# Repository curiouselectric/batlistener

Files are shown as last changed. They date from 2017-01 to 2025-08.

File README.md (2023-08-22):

# Bat Listener
Design files for the Bat Listener kit as sold by https://www.curiouselectric.co.uk/

The kit is available to purchase here:
https://www.curiouselectric.co.uk/products/bat-listener-2016

This repository holds the design files for the PCB, the enclosure and the instructions

The PCB files have been designed using KiCAD (http://kicad.org/) which is open source, multiple platform and free to download.

The Enclosure design files have been produced using CorelDraw (a paid for program) but are aklso available as .dxf patterns for cutting on a laser cutter.

The instructions are available as an open-office document and as a .pdf for direct download.

Any comments or info please email: hello@curiouselectric.co.uk

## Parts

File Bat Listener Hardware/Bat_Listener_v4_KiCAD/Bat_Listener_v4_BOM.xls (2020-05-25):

Reference | Value | Footprint | Datasheet | Description | Manufacturer | Manufacturer Part No
BT1 | BATTERY | REInnovationFootprint:Batt_Connector_Strain_Relief |  | PP3 Connector
C1 | 100u | REInnovationFootprint:C_1V7_TH
C10 | 1n | matts_components:C1_wide_lg_pad
C11 | 33n | matts_components:C1_wide_lg_pad
C12 | 470p | matts_components:C1_lg_pad
C13 | 470p | matts_components:C1_lg_pad
C14 | 100n | matts_components:C1_wide_lg_pad
C15 | 100u | REInnovationFootprint:C_1V7_TH
C16 | 100p | matts_components:C1_lg_pad
C2 | 100u | REInnovationFootprint:C_1V7_TH
C3 | 220n | matts_components:C1_wide_lg_pad
C4 | 47n | matts_components:C1_wide_lg_pad
C5 | 220u | REInnovationFootprint:C_1V7_TH
C6 | 47n | matts_components:C1_wide_lg_pad
C7 | 2n2 | matts_components:C1_wide_lg_pad
C8 | 1n5 | matts_components:C1_wide_lg_pad
C9 | 100p | matts_components:C1_lg_pad
D1 | 5V1 ZENER | REInnovationFootprint:TH_Diode_1 |  | 500mW 5V1 Zener
D2 | 1N4148 | REInnovationFootprint:TH_Diode_1
D3 | 1N4148 | REInnovationFootprint:TH_Diode_1
D4 | SENSE | reinnovation-footprints:TH_LED-5MM_larg_pad |  | LED Red 5mm
P1 | ULTRASON | reinnovation-footprints:TH_Ultra_sonic_Rx |  | 40kHz Ultrasonic Rx
P10 | LOGO1 | CuriousElectric3:TCEC_Words_13mm
P11 | LOGO2 | CuriousElectric3:CuriousElectric_globe_10mm
P12 | Hex_Spacer |  |  | 6 x HEX spacer 9mm M3 M-F
P2 | uP O/P | reinnovation-footprints:TH_Pin_Header_Straight_1x02
P3 | NO_Pb | REInnovationGraphics:PH_LOGO_NO_Pb
P4 | BAT | CuriousElectric3:Bat_Logo
P5 | PCB | reinnovation-footprints:PCB_50x100mm_PP3_CutOut
P6 | Enclosure
P7 | O/P | matts_components:SIL-2_lg_pad_1mm
P8 | Screws |  |  | 12 x M13 10mm Machine screws
P9 | Hex_Spacer |  |  | 6 x HEX spacer 9mm M-M
Q1 | BC337 | REInnovationFootprint:TO92-EBC_large_pad |  | NPN Transistor
R1 | 47k | REInnovationFootprint:TH_Resistor_1
R10 | 560k | REInnovationFootprint:TH_Resistor_1
R11 | 100 | REInnovationFootprint:TH_Resistor_1
R12 | 10k | REInnovationFootprint:TH_Resistor_1
R14 | 1k | REInnovationFootprint:TH_Resistor_1
R2 | 47k | REInnovationFootprint:TH_Resistor_1
R3 | 10 | REInnovationFootprint:TH_Resistor_1
R4 | 1k3 | REInnovationFootprint:TH_Resistor_1
R5 | 150k | REInnovationFootprint:TH_Resistor_1
R6 | 100k | REInnovationFootprint:TH_Resistor_1
R7 | 1k | REInnovationFootprint:TH_Resistor_1
R8 | 1k | REInnovationFootprint:TH_Resistor_1
R9 | 470k | REInnovationFootprint:TH_Resistor_1
RV1 | 22k | reinnovation-footprints:TH_PRESET_Thumb_Side |  | 20k Variable Resistor
SP1 | SPEAKER | reinnovation-footprints:TH_SPEAKER_36mm |  | 0.5W 8 ohm 36mm Speaker
SW1 | ON/OFF | reinnovation-footprints:SW_SPDT_R_Angle_ALIEX |  | Right Angle On/Off Slide Switch
U1 | LM386 | REInnovationFootprint:DIP-8_300_ELL | https://www.rapidonline.com/pdf/82-0264e.pdf | 325mW Power Amplifier | National Semiconductor | LM386N-1
U2 | TL074A | matts_components:DIP-14__300_ELL_lg_pad | https://www.rapidonline.com/pdf/82-0054_v1.pdf | Quad Op-Amp Bi-FET | Texas Instruments | TL074CN
U3 | 4024 | matts_components:DIP-14__300_ELL_lg_pad | https://www.rapidonline.com/pdf/83-0354_v1.pdf | 7 Stage Binary Counter | Texas Instruments | CD4024BE

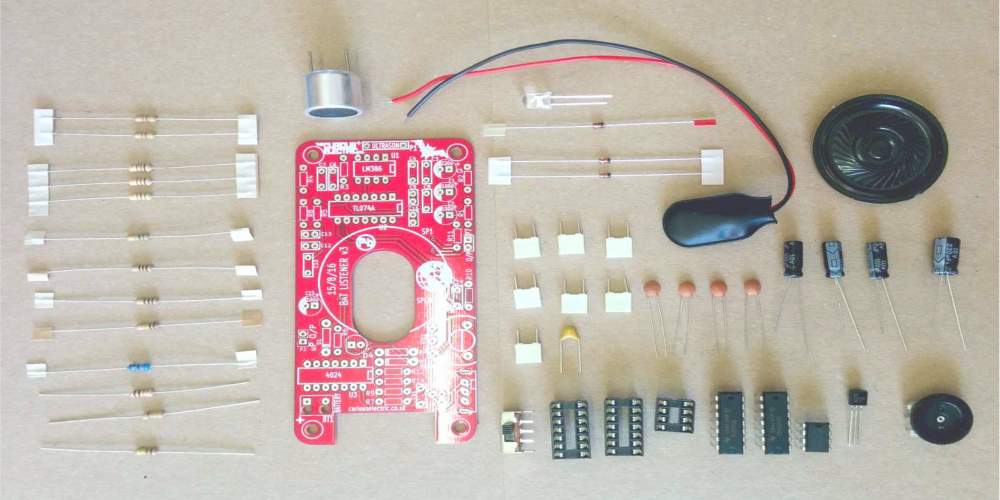
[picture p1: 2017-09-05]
Bat Listener Instructions/Photos/parts1_1000x5000.jpg

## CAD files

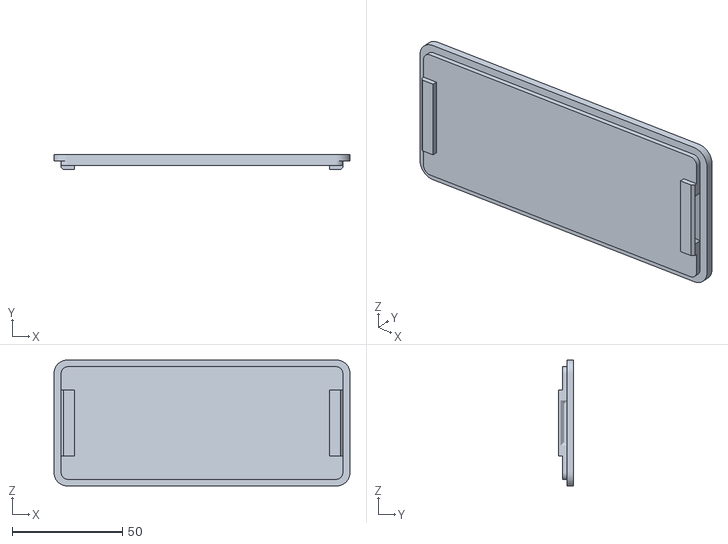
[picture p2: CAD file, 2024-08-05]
Bat_Listener_Enclosure/User Designed Cases/3D Printed Enclosure - Andy Evans/Ultrasonic Case Lid.stl
134.0 x 7.00 x 57.0

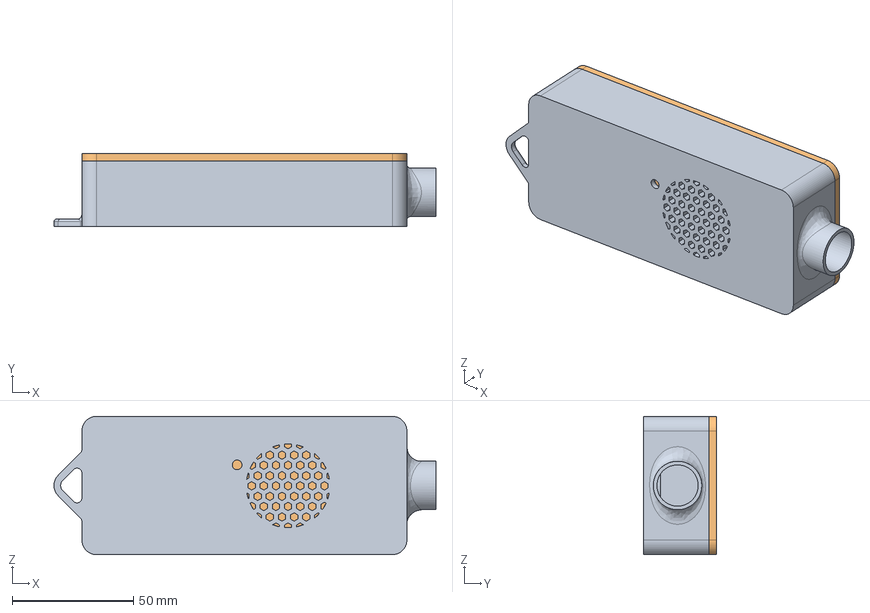
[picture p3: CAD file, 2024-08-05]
Bat_Listener_Enclosure/User Designed Cases/3D Printed Enclosure - Andy Evans/Ultrasonic Case.step
157.5 x 30.0 x 57.0 mm
Ultrasonic Case_1
Ultrasonic Case Lid

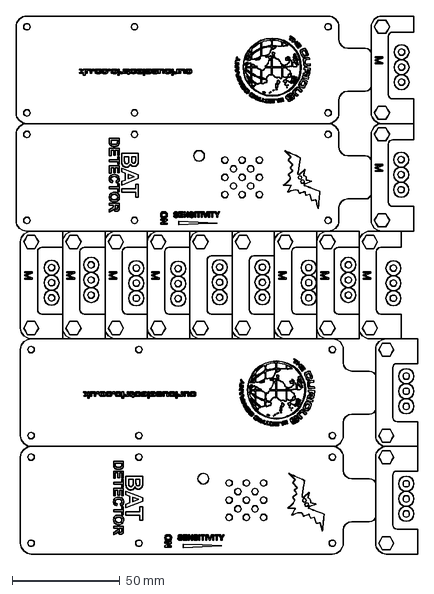
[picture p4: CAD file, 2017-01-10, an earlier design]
Bat_Listener_Enclosure/Curious Electric Standard Case/OLD/Bat Listener 2016 Enclosure v4.dxf
186.7 x 250.0 mm

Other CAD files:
Bat_Listener_Enclosure/User Designed Cases/3D Printed Enclosure - Andy Evans/Ultrasonic Case.stl

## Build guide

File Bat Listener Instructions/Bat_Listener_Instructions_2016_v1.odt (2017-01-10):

` | Bat Detector Kit Instructions

Date: | 18/10/16 | Version: | 1.0 | By: | Matt Little

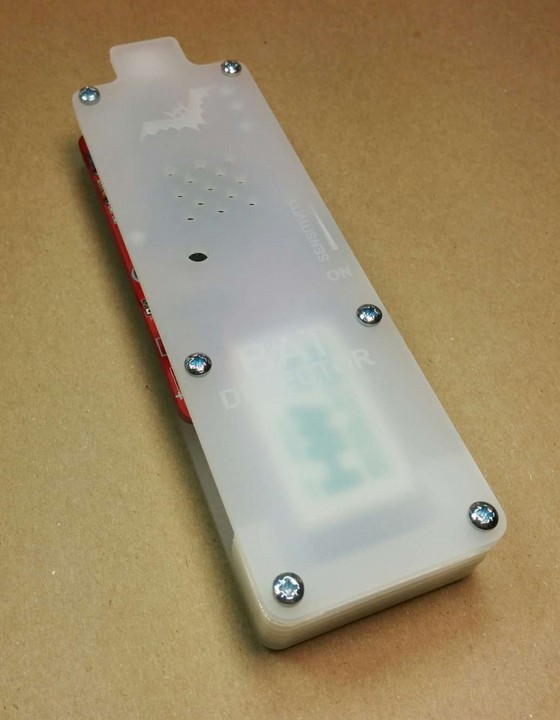
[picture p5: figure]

| Build your own Bat Detector! Bats use ultra-sonic pulses to navigate and to detect prey. These pulses are very high pitch (around 5 times the maximum frequency humans can hear). This electronic circuit converts the high pitched sounds produced by bats to a human-audiable level. It has a sensitivity control to adjust for different conditions. It can also be used to listen to other high frequencies such as peeling sticky tape, compact fluorescent lights and power supplies. This kit, although easy to build, requires quite a lot of soldering so will take in the region of 2-3 hours.

Parts included:

| | | Ultrasonic receiver | | LED | 5.1V Zener
| | | | | | | | 2 x 1N4148 Diodes
| | | | | | | | Speaker
| | | | | | | | PP3 battery clip
13 x Resistors | | | | | | | | 16 x Capacitors
| | | | | | | | Potentiometer
| | | | | | | | Transistor
| | PCB | | Switch | 3 x IC holders | 3 x ICs

Enclosure Parts:

Front | | 4 x spacers
Back
2mm end | | 6 x M3 Hex Spacers
4 x 3mm wide cut-out end
3mm end | | 6 x M3 12mm machine screws
| | 6 x M3 6mm machine screws

Parts list:

Item | Ref | Item | Ref
PP3 Battery Clip | BT1 | 47k Resistor | R1, R2
100uf Capacitor | C1, C2, C15 | 10 ohm Resistor | R3
220nf Capacitor | C3 | 1.3k Resistor | R4
47nf Capacitor | C4, C6 | 150k Resistor | R5
220uf Capacitor | C5 | 100k Resistor | R6
2.2nf Capacitor | C7 | 1k Resistor | R7,R8,R14
1.5nf Capacitor | C8 | 470k Resistor | R9
100pf Capacitor | C9, C16 | 560k Resistor | R10
1nf Capacitor | C10 | 100 ohm Resistor | R11
33nf Capacitor | C11 | 10k Resistor | R12
470pf Capacitor | C12,C13 | 20k Potentiometer | RV1
100nf Capacitor | C14 | 40mm Loudspeaker | SP1
5.1V Zener Diode | D1 | Switch | SW1
1N4148 small signal Diode | D2,D3 | LM386 Audio Amplifier IC | U1
5mm Red LED | D4 | TL074A Quad-comparator IC | U2
Ultrasonic Receiver | P1 | 4024 Counter IC | U3
BC337 Transistor | Q1
Enclosure
Front | x1 | 3mm PCB spacer rings | x4
Back | x1 | M3 Hex spacers 9mm | x6
2mm Clear Spacer | x1 | M3 6mm machine screws | x6
3mm Wide Spacer (marked "M") | x4 | M3 10mm machine screws | x6
3mm narrow spacer | x1

Tools required:

PCB Instructions:

Step: 1 | Solder resistors

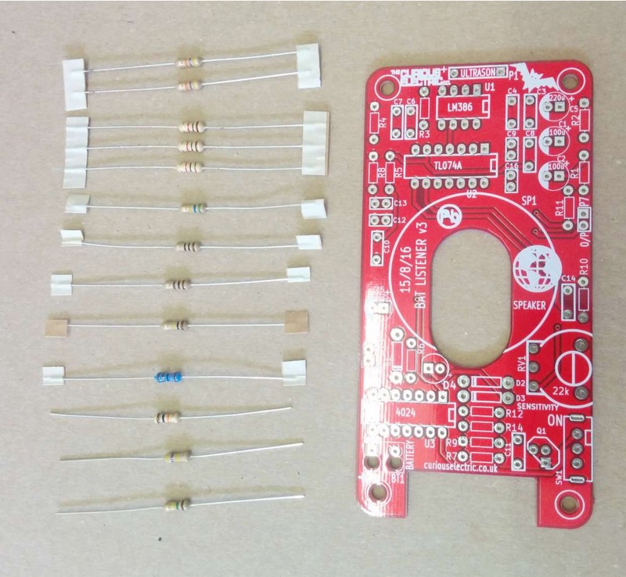
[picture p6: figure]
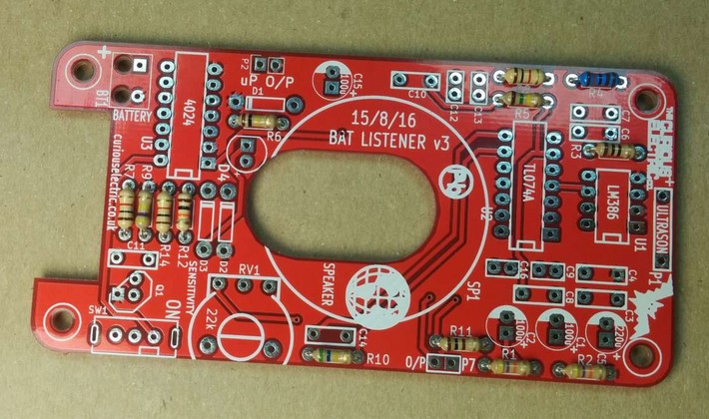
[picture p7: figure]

| | Value Ref Colour 47k R1, R2 Yellow, Violet, Orange, Gold 10 R3 Brown, Black, Black, Gold 1.3k R4 Brown, Orange, Red, Gold (This resistor is blue) 150k R5 Brown, Green, Yellow, Gold 100k R6 Brown, Black, Yellow, Gold 1k R7,R8,R14 Brown, Black, Red, Gold 470k R9 Yellow, Violet, Yellow, gold 560k R10 Green, Blue, Yellow, Gold 100 R11 Brown, Black, Brown, Gold 10k R12 Brown, Black, Orange, Gold Insert and solder the resistors. Polarity does not matter for resistors. Ensure they are soldered flat close to the PCB. Use a multimeter or colour code chart to ensure correct resistor values.

Step: 2 | Solder capacitors

First solder the non-polarised capacitors.

Orientation of these does not matter:

Value | Ref | Marking
220nf | C3 | .22K63 (cream box)
47nf | C4, C6 | 47nK100 (cream box)
2.2nf | C7 | 2n2K100 (cream box)
1.5nf | C8 | 152 (brown blob)
100pf | C9, C16 | 101 (brown disk)
1nf | C10 | 1nK100 (cream box)
33nf | C11 | 33nK100 (cream box)
470pf | C12,C13 | 471 (brown disk)
100nf | C14 | .1K63 (cream box)

Next solder the polarised capacitors. Ensure correct orientation of these components.

The negative lead is marked with a white strip. The positive lead is slightly longer than the negative. Align the positive lead with the + sign and the negative lead with the white PCB marking.

Value | Ref | Marking
100uf Capacitor | C1, C2, C15 | 10V 100uf
220uf Capacitor | C5 | 16V 220uf

Step: 3 | Solder diodes

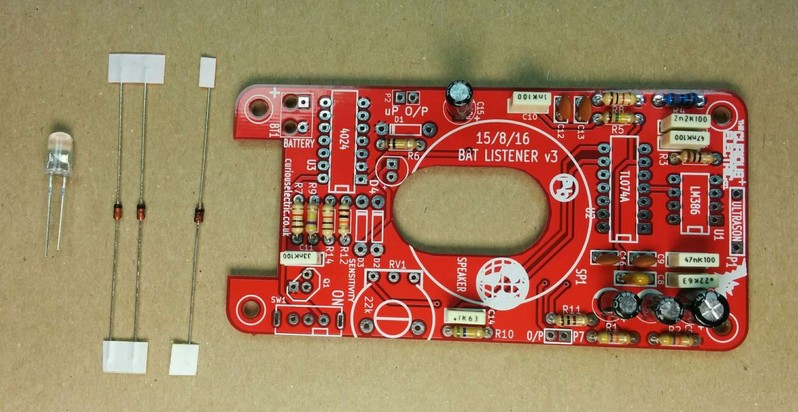
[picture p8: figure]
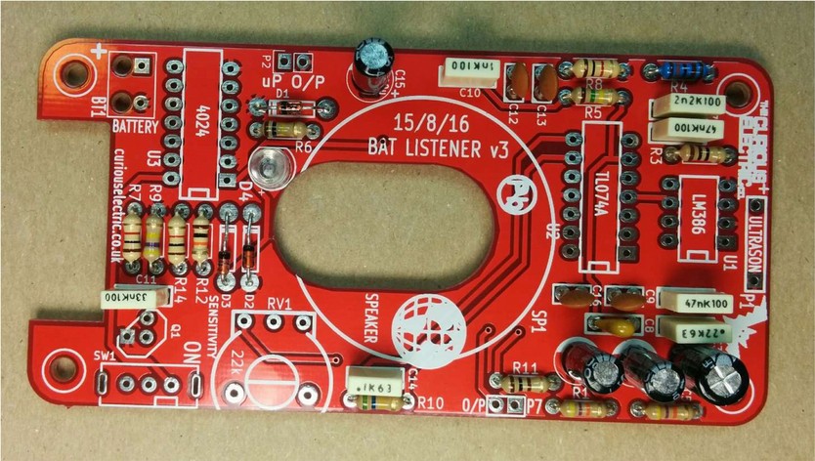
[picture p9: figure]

| | There are 4 diodes to solder. Ensure correct orientation for these components. First solder the LED into D4. The long lead is positive, so place that into the hole marked +. The negative side is slightly flat. Then solder the 5.1V zener diode into D1. This diode is on its own and has very tiny marking of “5V1”. Ensure the black band aligns with the white band marked on the PCB. The solder the remaining 2 diodes into D2 and D3. These have tiny markings saying “4148”. Ensure the black band aligns with the white band marked on the PCB.

Step: 4 | Solder transistor

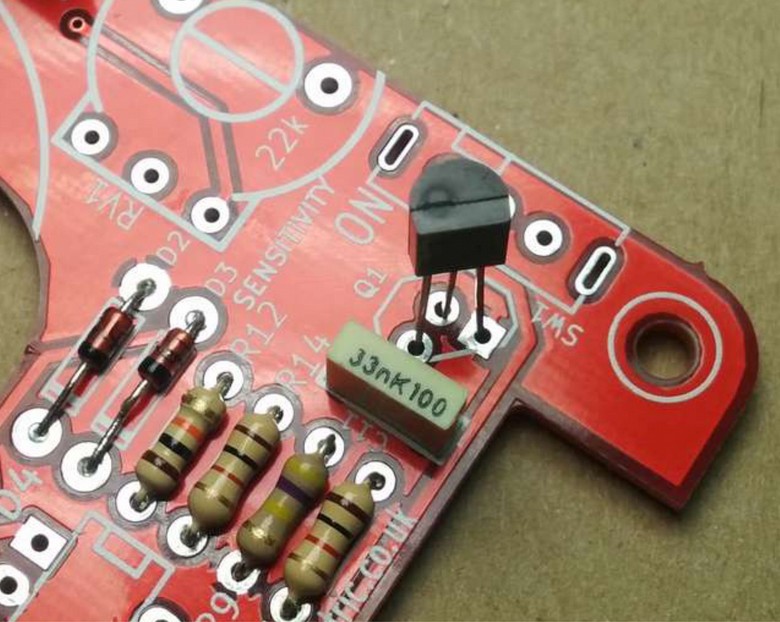
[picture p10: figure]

There is just one transistor to solder, Q1, BC337. Ensure the flat side of the transistor aligns with the PCB markings.

Step: 5 | Solder IC holders

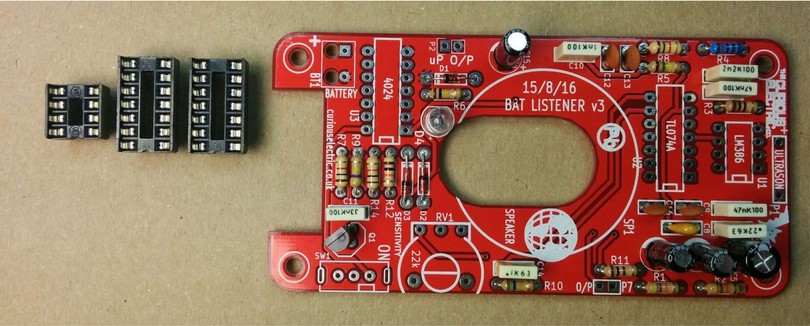
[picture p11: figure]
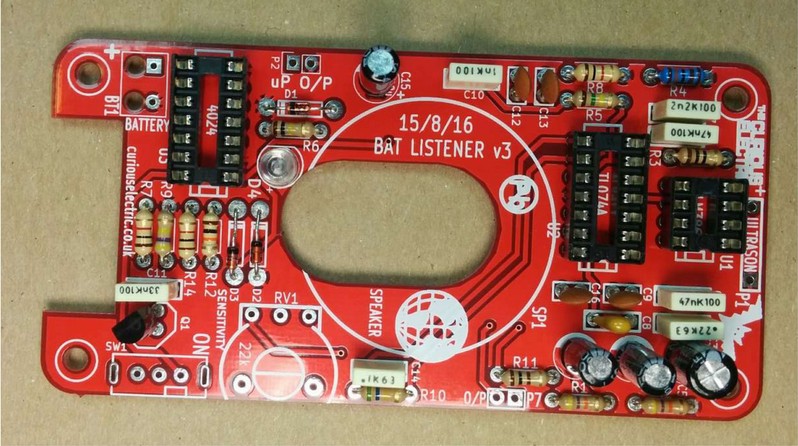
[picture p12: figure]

| | There are two 14pin IC holders and one 8 pin IC holder. These fit into the areas marked U1, U2 and U3. Ensure correct orientation! Ensure the notch on the holder aligns with the notch shown on the PCB.

Step: 6 | Solder Switch and Potentiometer

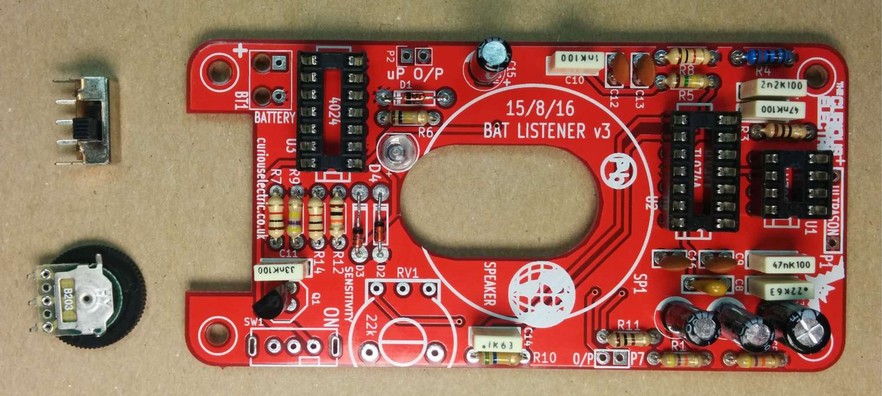
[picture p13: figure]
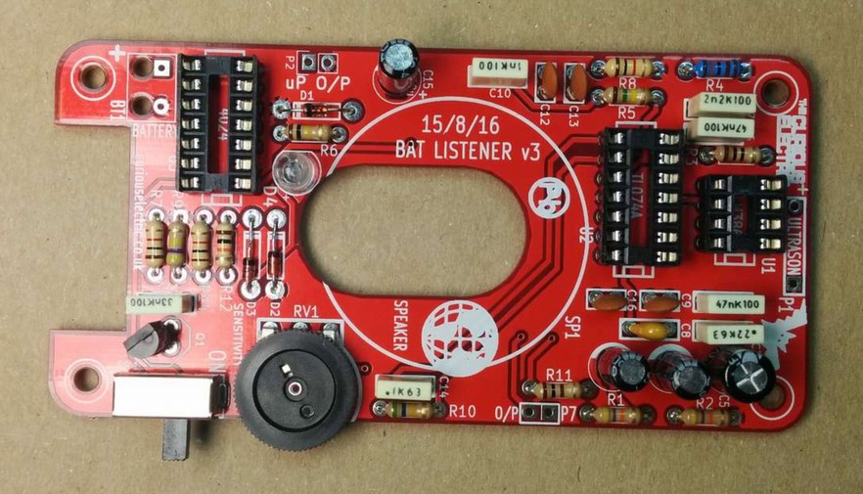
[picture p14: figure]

The switch fits into the holes marked SW1. The switch knob goes off the PCB. Solder all metal tabs. The potentiometer fits into the holes marked RV1. There are 5 pins to align and the pins might need slightly moving to ensure they align correctly. Solder all metal tabs.

Step: 7 | Solder Speaker

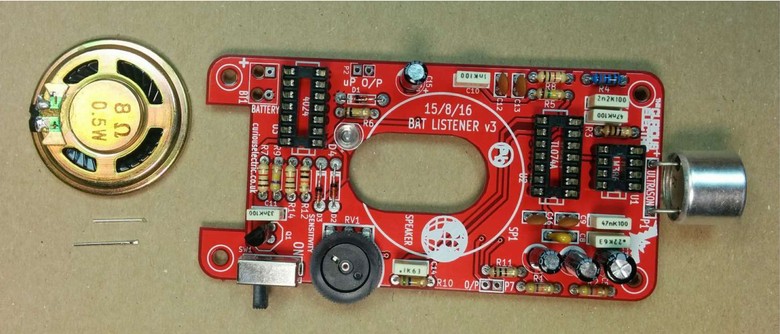
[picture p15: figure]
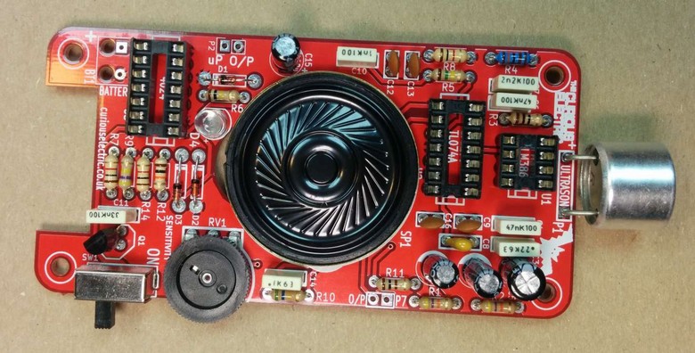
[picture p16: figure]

| | The speaker has a slightly unusual mounting method. The speaker base fits through the large hole in the PCB and the speaker tabs alight with the PCB tabs. Use an offcut of resistor lead and solder two small leads from the PCB (as shown). Then pt the speaker in place and solder the small wires to the speaker. This method holds the speaker in place, as well as being the electrical connection.

Step: 8 | Solder PP3 battery connector

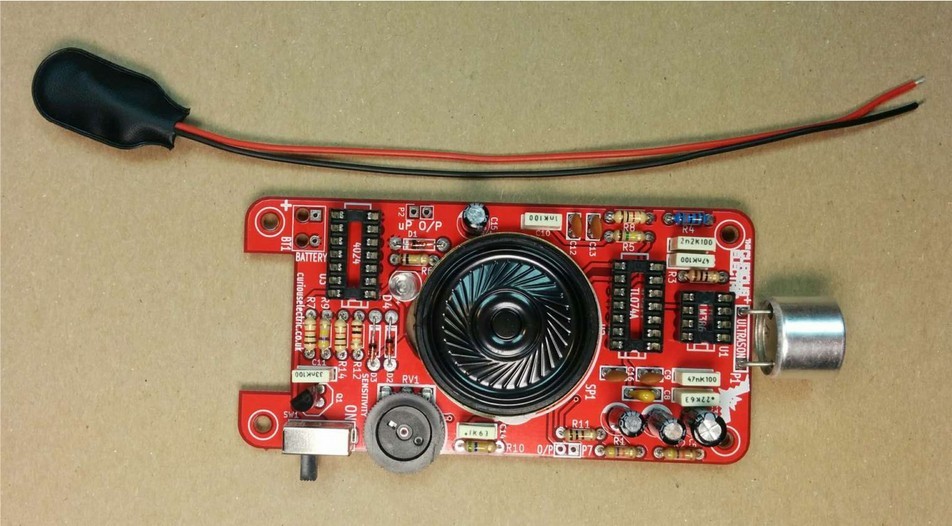
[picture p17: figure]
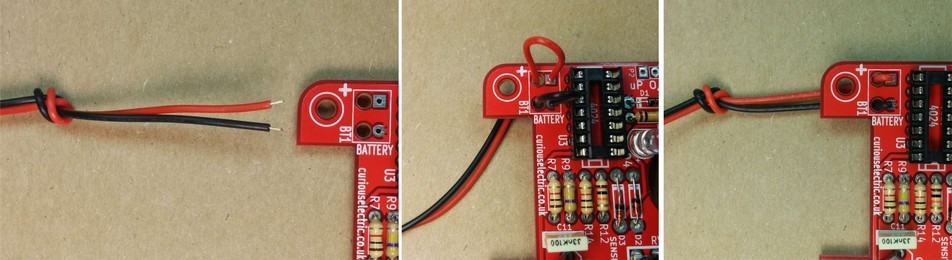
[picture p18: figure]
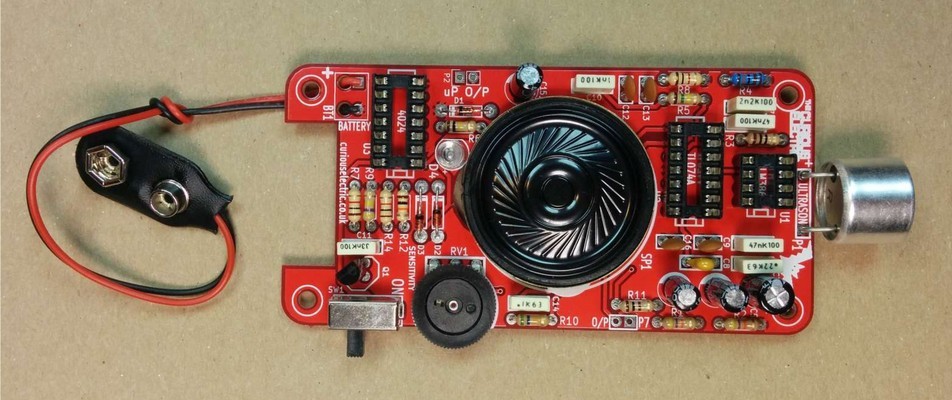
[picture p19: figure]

Nearly there! The PP3 battery clip as two wires: one positive (red) and one negative (black). I usually put a knot in the cable for strain relief. The cables then go through the larger holes and are fed back into the solder pads. The red cable goes through the hole to the pad marked “+”.

Step: 9 | Insert ICs

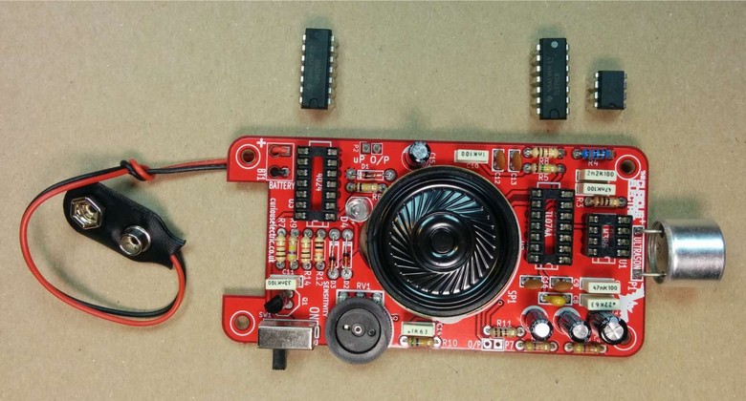
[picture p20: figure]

| | Now we need to insert the ICs into their holders. Ensure the notches align with the notches on the IC holders and the PCB. U1 is the LM386 (8 pin) U2 is the TL074A (14 pin) U3 is the 4024 (14 pin)

Step: 10 | Insert battery and test
Add a PP3 9V battery to the battery clip. Switch the unit on. You may hear a squeal from the device. Adjust potentiometer until you just do not hear any noise. The red LED should also flash when the speaker clicks. Use a reel of sticky tape to test. Slowly peel the tape off the reel and you should hear crackles from the speaker. This is picking up high frequency sound from the glue breaking. You can also test by pointing at a compact fluorescent light bulb. These switch at around 100kHz and hence give off ultrasonic noise.

Step: 16 | PCB is finished!
| | Have a nice cup of tea.

Enclosure Instructions:

Step: 1 | Push out laser-cut parts and peel off protective layer

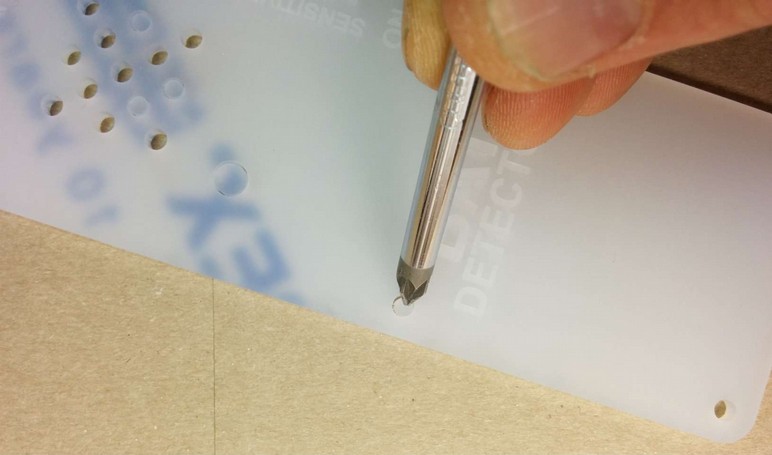
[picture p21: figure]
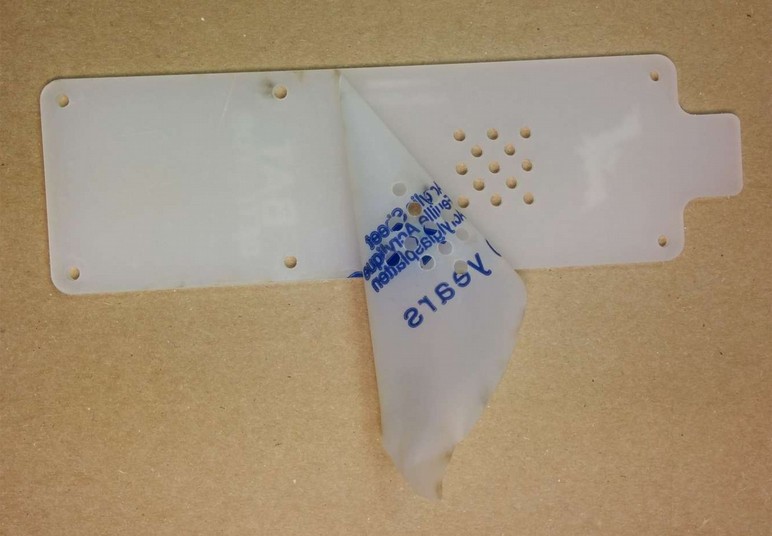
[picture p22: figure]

Sometimes not all the small laser-cut pieces have been removed. These can be pushed out using the point of a screwdriver. Only slight force should be required. There is a protective film on one side of the laser cut parts. This can be removed by peeling off the film.

Step: 2 | Screw down the PCB

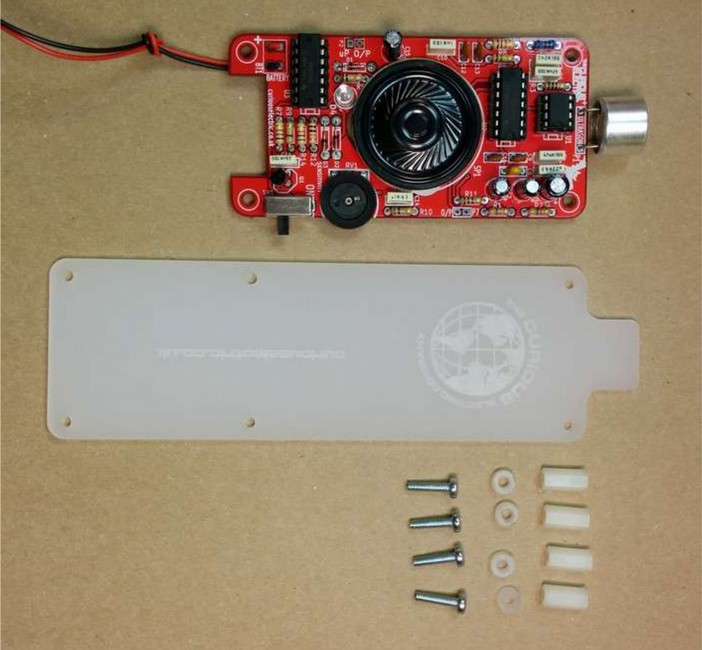
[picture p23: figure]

| | The PCB is held onto the back plate using the M3 10mm screws and the hex spacers. The back plate has the text facing to the back. The screws fit through the back plate then through a small circular spacer ring and then through the PCB. It is then held in place using the threaded hex spacer. Do this for all four corners of the PCB.

Step: 3 | Add end spacers

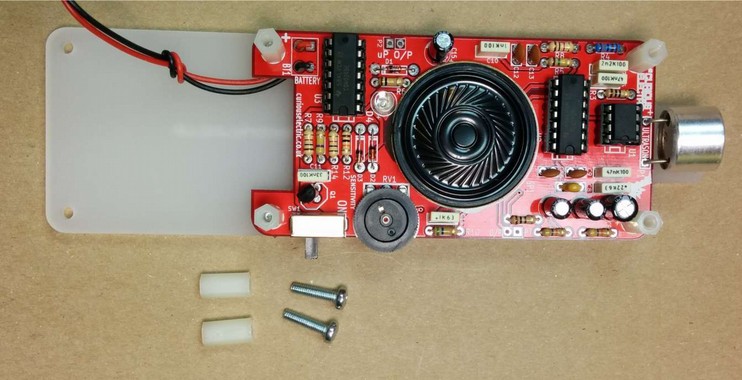
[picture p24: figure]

To hold the end spacers in place we again use the 10mm screws and 2 of the hex spacers. Put them through the back plate and slightly screw the hex spacer onto the screw. Do not fully tighten this, as it will need to spin to be adjusted in the next step.

Step: 4 | Add battery holders

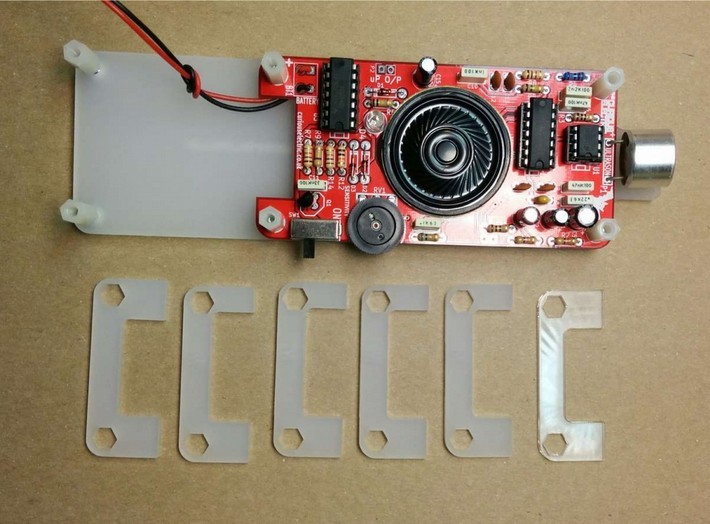
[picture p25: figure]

| | The battery holders are 6 spacers which holds one end of the battery, with the other end being held the notch in the PCB. There are three types of spacer: 1 x narrow 3mm spacer (in white frosted plastic) 4 x wide 3mm spacers (with an “M” etched on them). 1 x narrow 2mm spacer in clear plastic. These fit onto the hex spacers we just added. First add the narrow 3mm piece. Then the 4 wide 3mm pieces (marked “M”). Put the battery into the enclosure. The PP3 battery clip fits within the wider section, with the cable able to come out of the side. The final narrow 2mm space is put on top.

Step: 5 | Fit top cover

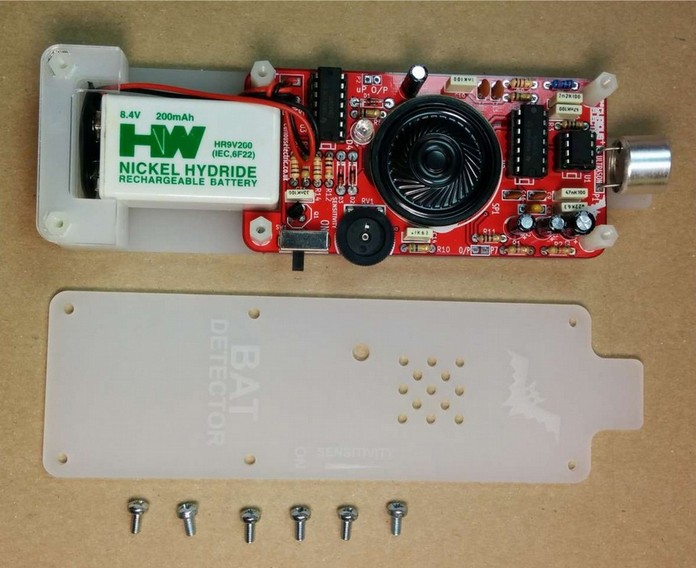
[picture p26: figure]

The front cover is then put on with the text facing upwards. Use the final 6 x 6mm M3 machine screws to hold the front cover in place. These fasten into the threaded hex spacers. Note: Some covers do not have the hole for the LED. The LED can be seen through the frosted plastic, so it is not needed.

Step: 6 | Finished!

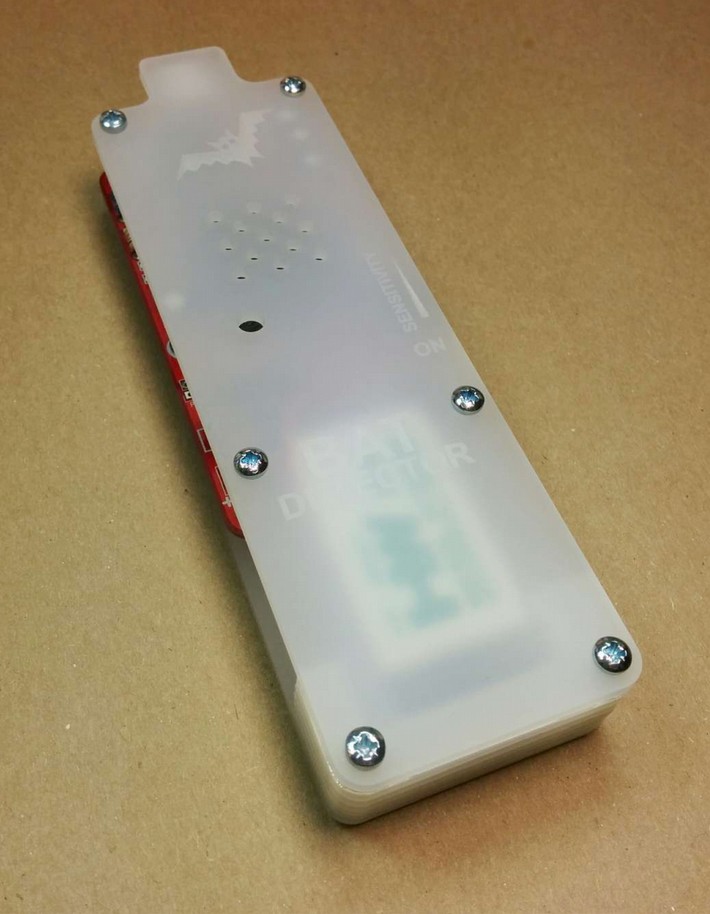
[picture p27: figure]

| | That is the unit finished! The on/off switch and the potentiometer are accessible via the side of the unit. You now have your own bat detector. There are many things you can investigate including: Nature: monitor bats, mice and rats Electrical: Check the sound from switching power supplies and fluorescent lights

Please note: This unit is NOT waterproof. Do NOT leave outside if it will get wet.

Contact details:

We would like you to be happy with this kit. If you are not happy for any reason then please contact us and we will help to sort it out.

Please email hello@curiouselectric.co.uk with any questions or comments.

Please tweet us at @curiouselectric

If any parts are missing from your kit then please email hello@curiouselectric.co.uk with details and, if possible, where the kit was purchased.

More technical information can be found via www.curiouselectric.co.uk

This kit has been designed and produced by:

The Curious Electric Company

hello@curiouselectric.co.uk

www.curiouselectric.co.uk

Hopkinson, 21 Station Street, Nottingham, NG2 3AJ, UK

History

This kit is based upon a circuit originally published by Elektor Electronics:

http://www.elektor.com/magazines/2011/november/simple-bat-detector.1971945.lynkx

and was originally developed as a workshop for Nottingham Hackspace: www.nottinghack.co.uk

Circuit Schematic

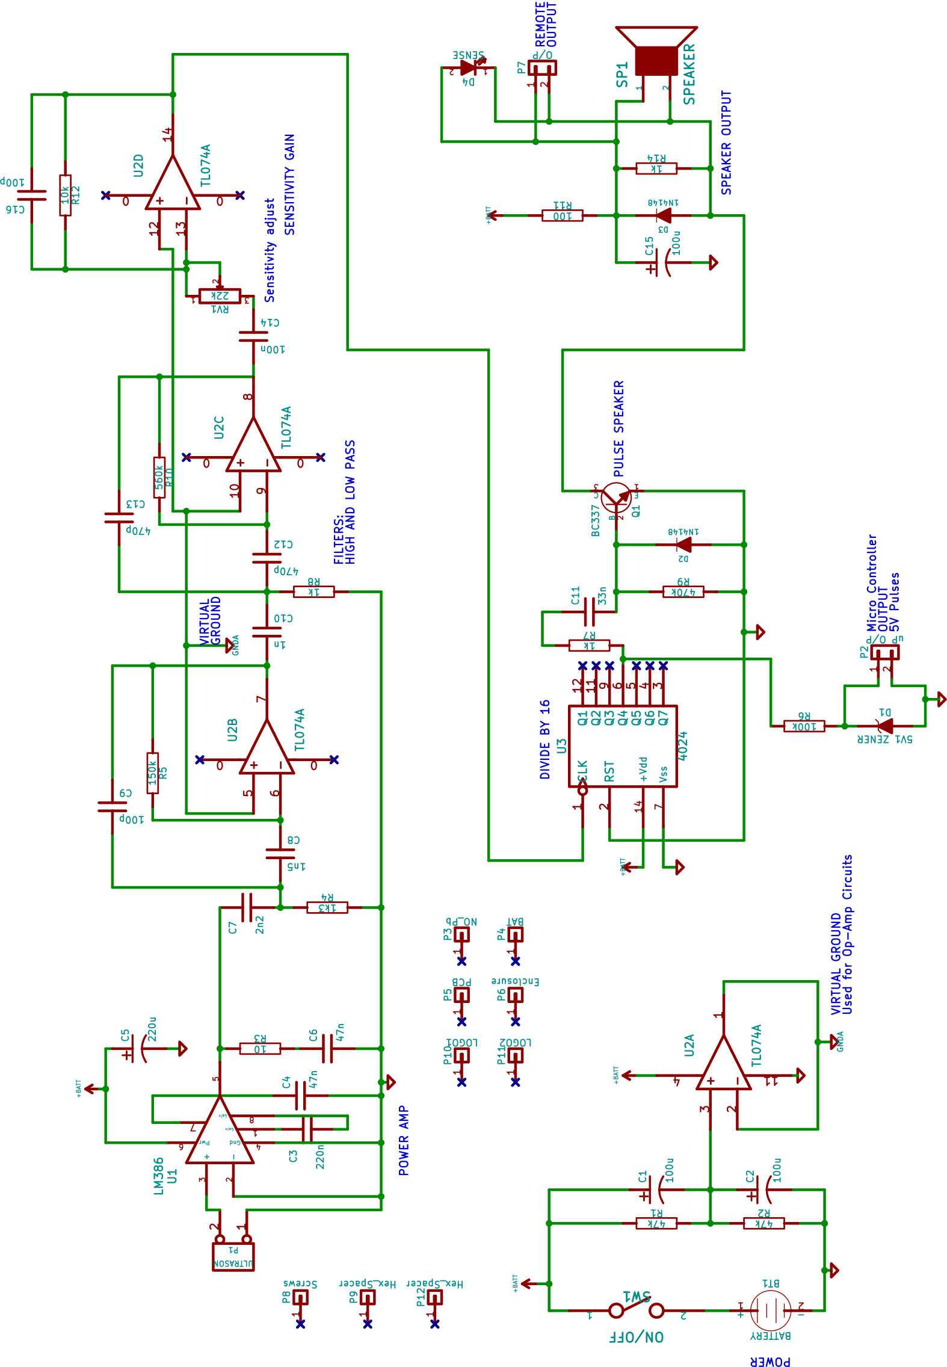
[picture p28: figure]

Resistor Colour Codes

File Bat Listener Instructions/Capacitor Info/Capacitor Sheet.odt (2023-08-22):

Capacitor Information

Due to changes in component suppliers your kit may have different styles of capacitors included.

Value | Ref | Marking | Image | Marking | Image
220nf | C3 | ‘.22K63’ | | ‘224’
47nf | C4, C6 | ‘47nK100’ | | ‘473’
2.2nf | C7 | ‘2n2K100’ | | ‘222’
1.5nf | C8 | ‘152’ | Also in blue
100pf | C9, C16 | ‘101’ | | ‘101’
1nf | C10 | ‘1nK100’ | | ‘102’
33nf | C11, C17 | ‘33nK100’ | Also in dark grey | ‘333’
470pf | C12,C13 | ‘471’ | | ‘471’
100nf | C14 | ‘.1K63’ or ‘.1J63‘ | | ‘104’
100uf | C1, C2, C15 | ‘10V 100uf’ | | Might have different voltages
220uf | C5 | ‘16V 220uf’ | | Might have different voltages

Capacitor Information

Due to changes in component suppliers your kit may have different styles of capacitors included.

Value | Ref | Marking | Image | Marking | Image
220nf | C3 | ‘.22K63’ | | ‘224’
47nf | C4, C6 | ‘47nK100’ | | ‘473’
2.2nf | C7 | ‘2n2K100’ | | ‘222’
1.5nf | C8 | ‘152’ | Also in blue
100pf | C9, C16 | ‘101’ | | ‘101’
1nf | C10 | ‘1nK100’ | | ‘102’
33nf | C11, C17 | ‘33nK100’ | Also in dark grey | ‘333’
470pf | C12,C13 | ‘471’ | | ‘471’
100nf | C14 | ‘.1K63’ or ‘.1J63‘ | | ‘104’
100uf | C1, C2, C15 | ‘10V 100uf’ | | Might have different voltages
220uf | C5 | ‘16V 220uf’ | | Might have different voltages

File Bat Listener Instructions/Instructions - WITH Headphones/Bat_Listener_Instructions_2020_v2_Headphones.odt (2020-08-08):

| Bat Detector Kit Instructions

Date: | 06/08/2020 | Version: | 5.0 | By: | Matt Little


| Build your own Bat Detector! Bats use ultra-sonic pulses to navigate and to detect prey. These pulses are very high pitch (around 5 times the maximum frequency humans can hear). This electronic circuit converts the high pitched sounds produced by bats to a human-audible level. It has a sensitivity control to adjust for different conditions. It can also be used to listen to other high frequencies such as peeling sticky tape, compact fluorescent lights and power supplies. This kit, although easy to build, requires quite a lot of soldering so will take in the region of 2-3 hours.

Parts included:

| | | 14 x Resistors | | | | | PP3 battery clip
PCB | | | | | | | | 17 x Capacitors
2 x 1N4148 Diodes
5.1 V Zener | | | | | | | | Potentiometer
| | | | | | | | Switch
Speaker
| LED | Transistor | | 3 x IC holders | 3 x ICs | 3.5mm Jack Socket | | Ultrasonic receiver

Enclosure Parts:

Front | | 4 x spacers
Back
2mm end (marked ‘6’) | | 6 x M3 Hex Spacers 12mm long
5 x 3mm thick spacers (marked ‘1’-’5’) | | 8 x M3 12mm machine screws
| | 4 x M3 6mm machine screws

Parts list:

Item | Ref | Item | Ref
PP3 Battery Clip | BT1 | 47k Resistor | R1, R2
100uf Capacitor | C1, C2, C15 | 10 ohm Resistor | R3
220nf Capacitor | C3 | 1.3k Resistor | R4
47nf Capacitor | C4, C6 | 150k Resistor | R5
220uf Capacitor | C5 | 10k Resistor | R6, R12
2.2nf Capacitor | C7 | 1k Resistor | R7, R8, R14
1.5nf Capacitor | C8 | 470k Resistor | R9
100pf Capacitor | C9, C16 | 560k Resistor | R10
1nf Capacitor | C10 | 100 ohm Resistor | R11, R13
33nf Capacitor | C11, C17 | 20k Potentiometer | RV1
470pf Capacitor | C12, C13 | 40mm Loudspeaker | SP1
100nf Capacitor | C14 | Switch | SW1
5.1V Zener Diode | D1 | LM386 Audio Amplifier IC | U1
1N4148 small signal Diode | D2,D3 | TL074 Quad-comparator IC | U2
5mm Red LED | D4 | 4024 Counter IC | U3
Ultrasonic Receiver | P1 | 3.5mm Headphone Jack Socket | J1
BC337 Transistor | Q1
Enclosure
Front | x1 | 3mm PCB spacer rings | x4
Back | x1 | M3 Hex spacers 9mm | x6
2mm clear plastic spacer (marked '6') | x1 | M3 6mm machine screws | x4
3mm frosted plastic spacer (numbered '1' - '5') | X5 | M3 12mm machine screws | x8

Tools required:

PCB Instructions:

Step: 1 | Solder resistors


Value | Ref | Colour
47k | R1, R2 | Yellow, Violet, Orange, Gold
10 | R3 | Brown, Black, Black, Gold
1.3k | R4 | Brown, Orange, Black, Brown, Brown
150k | R5 | Brown, Green, Yellow, Gold
10k | R6, R12 | Brown, Black, Orange, Gold
1k | R7, R8, R14 | Brown, Black, Red, Gold
470k | R9 | Yellow, Violet, Yellow, gold
560k | R10 | Green, Blue, Yellow, Gold
100 | R11, R13 | Brown, Black, Brown, Gold

Insert and solder the resistors.

Polarity does not matter for resistors.

Ensure they are soldered flat close to the PCB.

Note: Some resistors are blue – check the colour codes at the end of these instructions.

Use a multimeter or colour code chart to ensure correct resistor values.

Step: 2 | Solder capacitors

First solder the non-polarised capacitors.

Orientation of these does not matter:

Value | Ref | Marking
220nf | C3 | ‘224’ (brown blob)
47nf | C4, C6 | 47nK100 (cream box)
2.2nf | C7 | ‘222’ (brown blob)
1.5nf | C8 | 152 (brown blob)
100pf | C9, C16 | 101 (brown disk)
1nf | C10 | 1nK100 (cream box)
33nf | C11, C17 | ‘333’ (brown blob)
470pf | C12,C13 | 471 (brown disk)
100nf | C14 | ‘104’ (brown blob)

Note: You may need a magnifying glass for reading the text on these capacitors.

Next solder the polarised capacitors. Ensure correct orientation of these components.

The negative lead is marked with a white strip. The positive lead is slightly longer than the negative. Align the positive lead with the + sign and the negative lead with the white PCB marking.

Value | Ref | Marking
100uf Capacitor | C1, C2, C15 | 10V 100uf
220uf Capacitor | C5 | 16V 220uf

Step: 3 | Solder diodes


| | There are 4 diodes to solder. Ensure correct orientation for these components. First solder the LED into D4. The long lead is positive, so place that into the hole marked +. The negative side is slightly flat. Then solder the 5.1 V zener diode into D1. This diode is on it’s own and has very tiny marking of “5V1”. Ensure the black band aligns with the white band marked on the PCB. Then solder the remaining 2 diodes into D2 and D3. These have tiny markings saying “4148”. Ensure the black band aligns with the white band marked on the PCB.

Step: 4 | Solder transistor
There is just one transistor to solder, Q1, BC337. Ensure the flat side of the transistor aligns with the PCB markings.

Step: 5 | Solder IC holders


| | There are two 14 pin IC holders and one 8 pin IC holder. These fit into the areas marked U1, U2 and U3. Ensure correct orientation! Ensure the notch on the holder aligns with the notch shown on the PCB.

Step: 6 | Solder Switch and Potentiometer


The switch fits into the holes marked SW1. The switch knob goes off the PCB. Solder all metal tabs. The potentiometer fits into the holes marked RV1. There are 5 pins to align and the pins might need slightly moving to ensure they align correctly. Solder all metal tabs.

Step: 7 | Solder the ultrasonic receiver

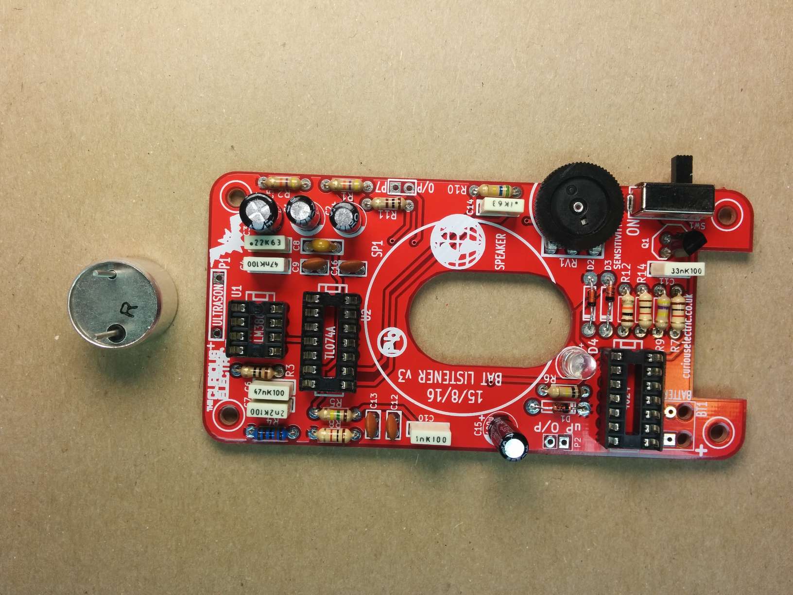
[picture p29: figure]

The ultrasonic receiver has two pins, one is attached to the metal case of the unit, the other has a small ring around it. The pin with the small ring around it is the +ve connection and this pin fits in the hole with the + symbol. The ground fits next to the indicator P1. Carefully bend the legs to 90 degrees to the receiver is facing away from the PCB.

Step: 8 | Solder the headphone socket
The 3.5mm headphone jack socket is soldered on the back of the PCB. This must be soldered before the speaker. Insert from the underside into ‘J1’ and solder from the top side of the PCB.

Step: 9 | Solder Speaker

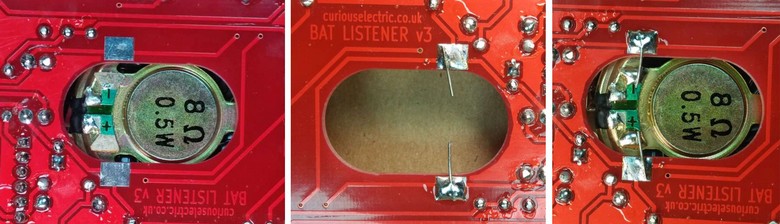
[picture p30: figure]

| | The speaker has a slightly unusual mounting method. The speaker base fits through the large hole in the PCB and the speaker tabs align with the PCB tabs. Use an off-cut of resistor lead and solder two small leads from the PCB (as shown). Carefully bend the legs to 90 degrees before soldering in position facing away from the PCB. Then put the speaker in place and solder the small wires to the speaker. This method holds the speaker in place, as well as being the electrical connection.

Step: 10 | Solder PP3 battery connector


Nearly there! The PP3 battery clip as two wires: one positive (red) and one negative (black). I usually put a knot in the cable for strain relief. The cables then go through the larger holes from the underside and are fed back into the solder pads. The red cable goes through the hole to the pad marked “+”.

Step: 11 | Insert ICs


| | Now we need to insert the ICs into their holders. Ensure the notches align with the notches on the IC holders and the PCB. U1 is the LM386 (8 pin) U2 is the TL074 (14 pin) U3 is the 4024 (14 pin)

Step: 12 | Insert battery and test
Add a PP3 9V battery to the battery clip. Switch the unit on. You may hear a squeal from the device. Adjust the potentiometer until you just do not hear any noise. The red LED should also flash when the speaker clicks. Use a reel of sticky tape to test. Slowly peel the tape off the reel and you should hear crackles from the speaker. This is picking up high frequency sound from the glue breaking. You can also test by pointing at a compact fluorescent light bulb. These switch at around 100 kHz and hence give off ultrasonic noise.

Step: 13 | PCB is finished!
| | Have a nice cup of tea.

Enclosure Instructions:

Step: 1 | Push out laser-cut parts and peel off protective layer


Sometimes not all the small laser-cut pieces have been removed. These can be pushed out using the point of a screwdriver. Only slight force should be required. There is a protective film on one side of the laser cut parts. This can be removed by peeling off the film.

Step: 2 | Screw down the PCB


| | The PCB is held onto the back plate using 4 of the M3 12mm screws and the hex spacers. The back plate has the text facing to the back. The screws fit through the back plate then through a small circular spacer ring and then through the PCB. It is then held in place using the threaded hex spacer. Do this for all four corners of the PCB. Note: This photo does not show the headphone socket, which should align with the cut-out of the plastic base.

Step: 3 | Add end spacers


To hold the end spacers in place we again use the 12mm screws and 2 of the hex spacers. Put them through the back plate and slightly screw the hex spacer onto the screw. Do not fully tighten this, as it will need to spin to be adjusted in the next step.

Step: 4 | Add battery holders


1

2

3

4

5

6

The battery holders are 6 spacers which holds one end of the battery, with the other end being held the notch in the PCB.

There are three types of spacer:

1 x narrow 3mm spacer (in white frosted plastic, marked “1”)

4 x wide 3mm spacers (marked “2”, ”3”, ”4” & “5” ).

1 x narrow 2mm spacer in clear plastic (marked “6”).

These fit onto the hex spacers we just added.

First add the narrow 3mm piece(marked “1”).

Then the 4 wide 3mm pieces (marked “2”, ”3”, ”4” & “5”).

Put the battery into the enclosure. The PP3 battery clip fits within the wider section, with the cable able to come out of the side.

The final narrow 2mm spacer (marked “6”) is put on top.

Step: 5 | Fit top cover


The front cover is then put on with the text facing upwards. Use the 4 x 6mm M3 machine screws to hold the front cover in place to the PCB holes and the final 2 x 12mm M3 machine screws to hold the end spacers in place. These fasten into the threaded hex spacers. Note: Some covers do not have the hole for the LED. The LED can be seen through the frosted plastic, so it is not needed.

Step: 6 | Finished!


| | That is the unit finished! The on/off switch and the potentiometer are accessible via the side of the unit. You now have your own bat detector. There are many things you can investigate including: Nature: monitor bats, mice and rats Electrical: Check the sound from switching power supplies and fluorescent lights

Please note: This unit is NOT waterproof. Do NOT leave outside if it will get wet.

Contact details:

We would like you to be happy with this kit. If you are not happy for any reason then please contact us and we will help to sort it out.

Please email hello@curiouselectric.co.uk with any questions or comments.

Please tweet us at @curiouselectric

If any parts are missing from your kit then please email hello@curiouselectric.co.uk with details and, if possible, when and where the kit was purchased.

More technical information can be found via www.curiouselectric.co.uk

This kit has been designed and produced by:

The Curious Electric Company

hello@curiouselectric.co.uk

www.curiouselectric.co.uk

Unit 23, Block D, Hartley Business Centre, Haydn Rd, Nottingham, NG5 1DG, UK

# History

This kit is based upon a circuit originally published by Elektor Electronics: http://www.elektor.com/magazines/2011/november/simple-bat-detector.1971945.lynkx

and was originally developed as a workshop for Nottingham Hackspace: www.nottinghack.co.uk

Circuit Schematic

Resistor Colour Codes

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
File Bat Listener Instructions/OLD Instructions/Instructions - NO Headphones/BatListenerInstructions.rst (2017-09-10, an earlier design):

Bat Listener Instructions
=========================

*By: Matthew Little*

*Date: 9th Sept 2017*

*hello@curiouselectric.co.uk*

Overview
--------

Build your own Bat Detector!


   
Bats use ultra-sonic pulses to navigate and to detect prey. These pulses are very high pitch (around 5 times the maximum frequency humans can hear). 

This electronic circuit converts the high pitched sounds produced by bats to a human-audiable level. 

It has a sensitivity control to adjust for different conditions.

It can also be used to listen to other high frequencies such as peeling sticky tape, compact fluorescent lights and power supplies.

This kit, although easy to build, requires quite a lot of soldering so will take in the region of 2-3 hours.

Components
----------

PCB and components
------------------

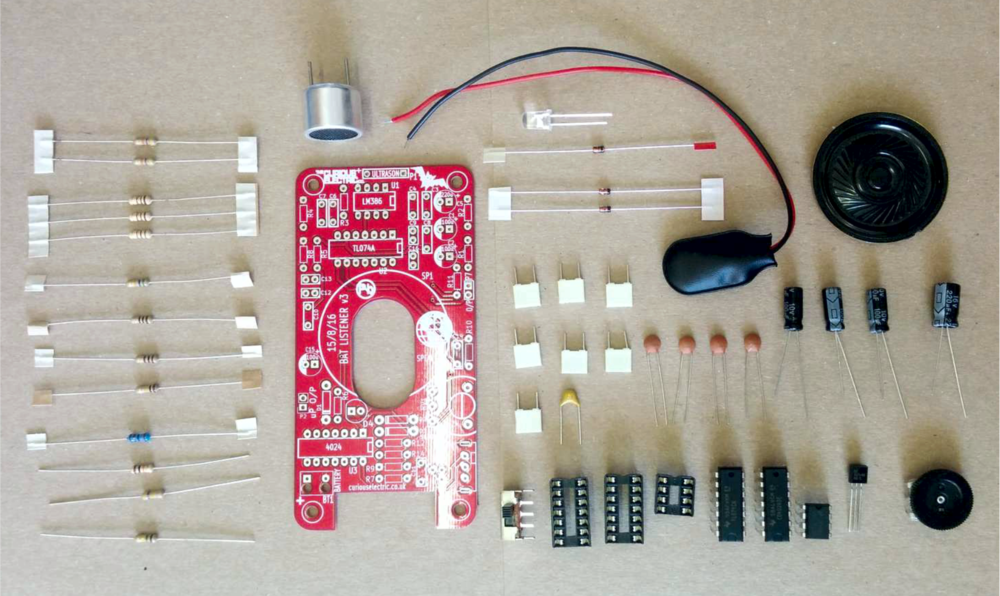
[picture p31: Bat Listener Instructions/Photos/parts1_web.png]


The kit contains the following electronic components:

+-------------------------+-----------+----------+---------------+
| Component Name          | Value     | Quantity |  Reference    |
+======+==================+===========+==========+===============+
| PP3 Battery Clip        |           |  1       |  BT1          |
+-------------------------+-----------+----------+---------------+
| 100uf Capacitor         | 100uf     |  3       |  C1, C2, C15  |
+-------------------------+-----------+----------+---------------+
| 220nf Capacitor         | 220nf     |  1       |  C3           |
+-------------------------+-----------+----------+---------------+
| 47nf Capacitor          | 47nf      |  2       |  C4, C6       |
+-------------------------+-----------+----------+---------------+
| 220uf Capacitor         | 220uf     |  1       |  C5           |
+-------------------------+-----------+----------+---------------+
| 2.2nf Capacitor         | 2.2nf     |  1       |  C7           |
+-------------------------+-----------+----------+---------------+
| 1.5nf Capacitor         | 1.5nf     |  1       |  C8           |
+-------------------------+-----------+----------+---------------+
| 100pf Capacitor         | 100pf     |  2       |  C9, C16      |
+-------------------------+-----------+----------+---------------+
| 1nf Capacitor           | 1nf       |  1       |  C10          |
+-------------------------+-----------+----------+---------------+
| 33nf Capacitor          | 33nf      |  1       |  C11          |
+-------------------------+-----------+----------+---------------+
| 470pf Capacitor         | 470pf     |  2       |  C12,C13      |
+-------------------------+-----------+----------+---------------+
| 100nf Capacitor         | 100nf     |  1       |  C14          |
+-------------------------+-----------+----------+---------------+
| 3.3V Zener Diode        | 3.3V      |  1       |  D1           |
+-------------------------+-----------+----------+---------------+
| Diode                   | 1N4148    |  2       |  D2,D3        |
+-------------------------+-----------+----------+---------------+
| 5mm Red LED             | LED       |  1       |  D4           |
+-------------------------+-----------+----------+---------------+
| Ultrasonic Receiver     |           |  1       |  P1           |
+-------------------------+-----------+----------+---------------+
| Transistor              | BC337     |  1       |  Q1           |
+-------------------------+-----------+----------+---------------+
| Resistor                | 47k       |  2       | R1, R2        |
+-------------------------+-----------+----------+---------------+
| Resistor                | 10        |  1       | R3            |
+-------------------------+-----------+----------+---------------+
| Resistor                | 1.3k      |  1       | R4            |
+-------------------------+-----------+----------+---------------+
| Resistor                | 150k      |  1       | R5            |
+-------------------------+-----------+----------+---------------+
| Resistor                | 100k      |  1       | R6            |
+-------------------------+-----------+----------+---------------+
| Resistor                | 1k        |  3       | R7,R8,R14     |
+-------------------------+-----------+----------+---------------+
| Resistor                | 470k      |  1       | R9            |
+-------------------------+-----------+----------+---------------+
| Resistor                | 560k      |  1       | R10           |
+-------------------------+-----------+----------+---------------+
| Resistor                | 100       |  1       | R11           |
+-------------------------+-----------+----------+---------------+
| Resistor                | 10k       |  1       | R12           |
+-------------------------+-----------+----------+---------------+
| Potentiometer           | 20k       |  1       | RV1           |
+-------------------------+-----------+----------+---------------+
| 40mm Loudspeaker        |           |  1       | SP1           |
+-------------------------+-----------+----------+---------------+
| Switch                  |           |  1       | SW1           |
+-------------------------+-----------+----------+---------------+
| Audio Amplifier IC      | LM386     |  1       | U1            |
+-------------------------+-----------+----------+---------------+
| Quad-comparator IC      | TL074A    |  1       | U2            |
+-------------------------+-----------+----------+---------------+
| Counter IC              | 4024      |  1       | U3            |
+-------------------------+-----------+----------+---------------+
| PCB                     |           |  1       |               |
+-------------------------+-----------+----------+---------------+

Enclosure parts
---------------

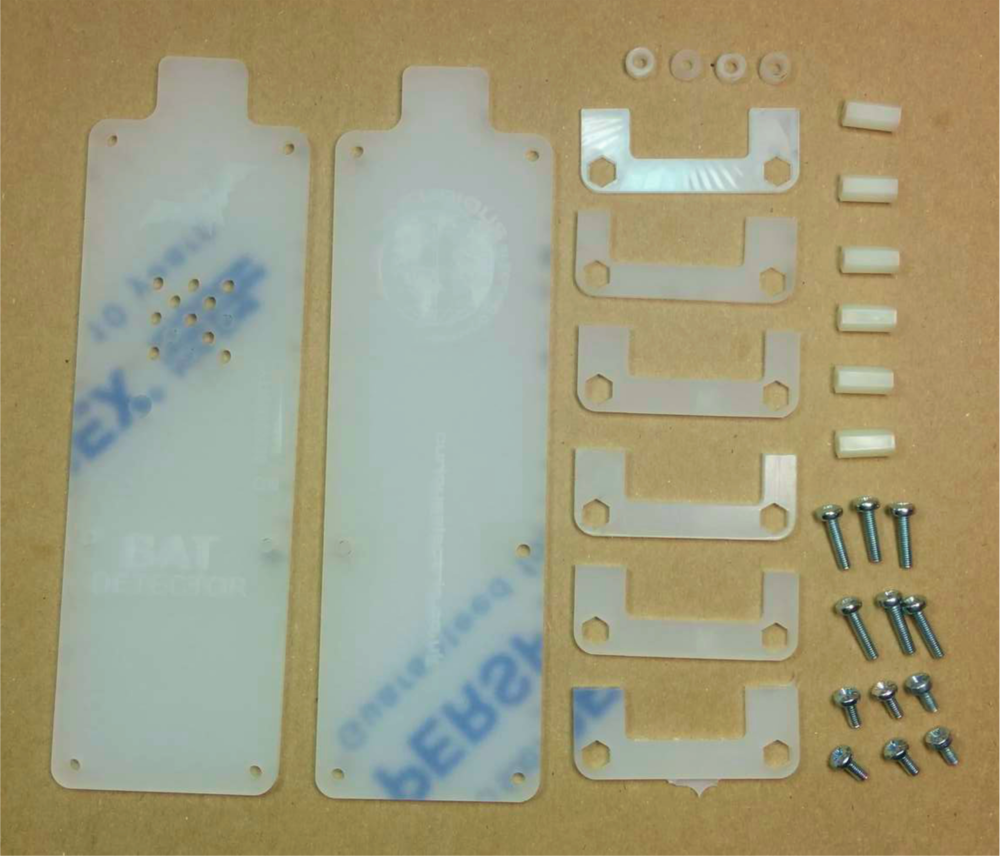
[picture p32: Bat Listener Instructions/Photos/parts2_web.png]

   
+---------------+--------------------------------------------+----------+ 
| Item          | Description and notes                      | Quantity |
+======+========+============================================+==========+
| Front         | 3mm Frosted Acrylic                        | 1        |
+---------------+--------------------------------------------+----------+ 
| Back          | 3mm Frosted Acrylic                        | 1        |
+---------------+--------------------------------------------+----------+ 
| Spacer levels | 3mm Frosted Acrylic                        | 4        |
+---------------+--------------------------------------------+----------+ 
| 3mm Spacer    | 3mm Frosted Acrylic. Marked with number    | 1        |
+---------------+--------------------------------------------+----------+ 
| 2mm Spacer    | 2mm clear Acrylic. Marked '6'              | 1        |
+---------------+--------------------------------------------+----------+ 
| Hex Spacer    | Nylon, M3 9mm Hex spacer                   | 6        |
+---------------+--------------------------------------------+----------+ 
| 6/8mm Screw   | M3, 6 or 8mm long Macine screw             | 6        |
+---------------+--------------------------------------------+----------+ 
| 6/8mm Screw   | M3, 6 or 8mm long Macine screw             | 6        |
+---------------+--------------------------------------------+----------+ 

Tools required
--------------

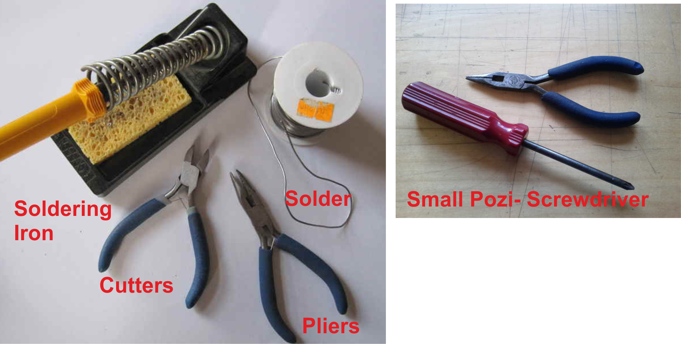
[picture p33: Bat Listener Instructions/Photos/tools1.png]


The main tools required are: 

- Soldering Iron, 
- Solder,
- Side cutters,
- Screw driver (pozi-head, small),
- Small pliers.

A useful guide for learning to solder is available here:

https://cdn.shopify.com/s/files/1/0943/8168/files/soldercomic.pdf

And a more detaileld guide is available here:

https://cdn.shopify.com/s/files/1/0943/8168/files/FullSolderComic_EN.pdf

Step 1: Solder resistors
------------------------



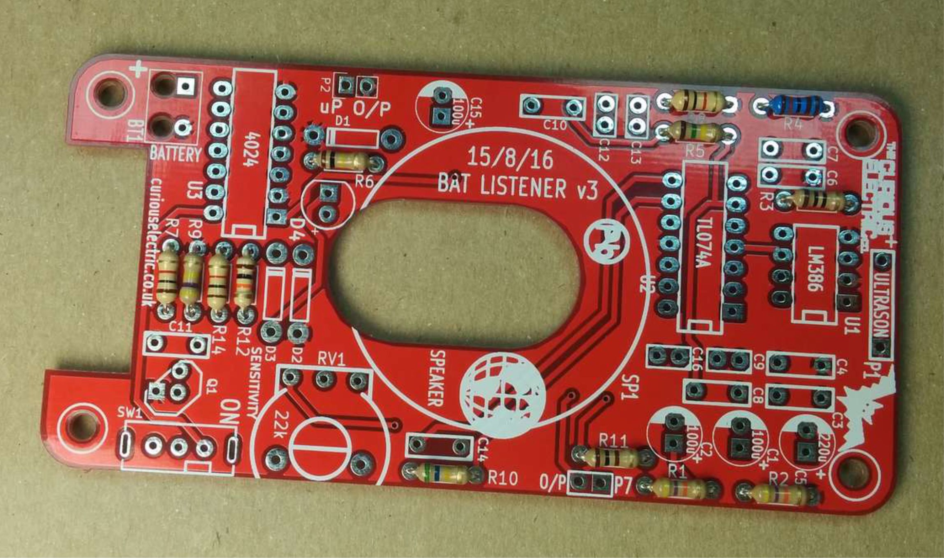
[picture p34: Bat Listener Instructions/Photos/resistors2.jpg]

   
These resistors are:

+------------+--------------------------------------+-------------+
| Value      | Colours                              | Reference   |
+============+======================================+=============+
| 47k ohm    | Yellow, Violet, Orange, Gold         | R1,R2       |
+------------+--------------------------------------+-------------+
| 10 ohm     | Brown, Black, Black, Gold            | R3          |
+------------+--------------------------------------+-------------+
| 1.3k ohm*  | Brown, Orange, Black, Brown, Brown   | R4          |
+------------+--------------------------------------+-------------+
| 150k ohm   | Brown, Green, Yellow, Gold           | R5          |
+------------+--------------------------------------+-------------+
| 10k ohm    | Brown, Black, Orange, Gold           | R6          |
+------------+--------------------------------------+-------------+
| 1k ohm     | Brown, Black, Red, Gold              | R7, R8, R14 |
+------------+--------------------------------------+-------------+
| 470k ohm   | Yellow, Violet, Yellow, Gold         | R9          |
+------------+--------------------------------------+-------------+
| 560k ohm   | Green, Blue, Yellow, Gold            | R10         |
+------------+--------------------------------------+-------------+
| 100 ohm    | Brown, Black, Brown, Gold            | R11         |
+------------+--------------------------------------+-------------+
| 10k ohm    | Brown, Black, Orange, Gold           | R12         |
+------------+--------------------------------------+-------------+

* = Note: This resistor is blue lcoured and has 5 bands.

The resistors do not have a polarity and can be soldered either way around.

Ensure they are soldered flat close to the PCB.

Use a multimeter or colour code chart to ensure correct resistor values.

Step 2: Solder the capacitors
-----------------------------

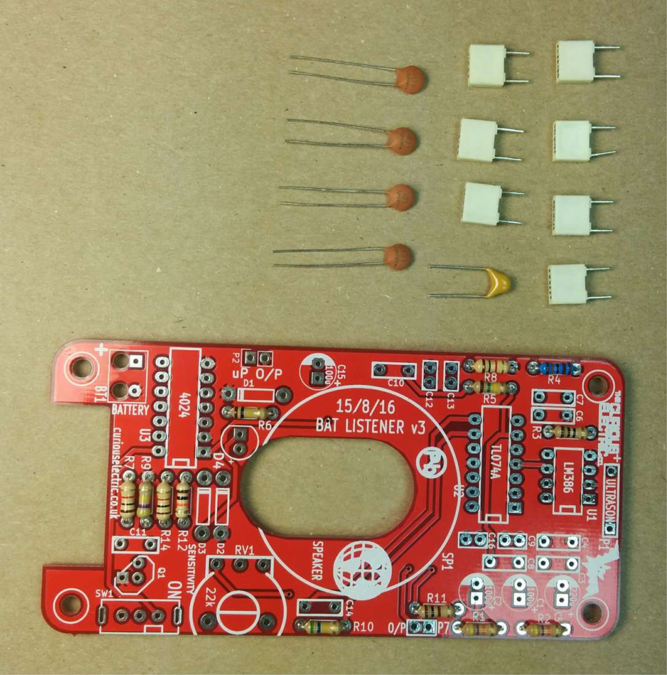
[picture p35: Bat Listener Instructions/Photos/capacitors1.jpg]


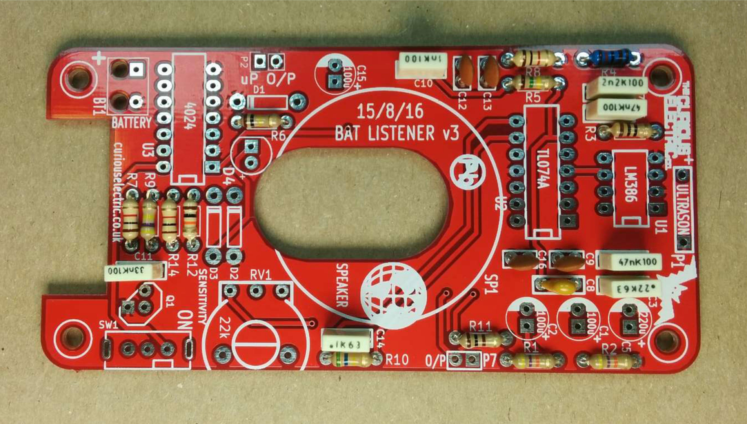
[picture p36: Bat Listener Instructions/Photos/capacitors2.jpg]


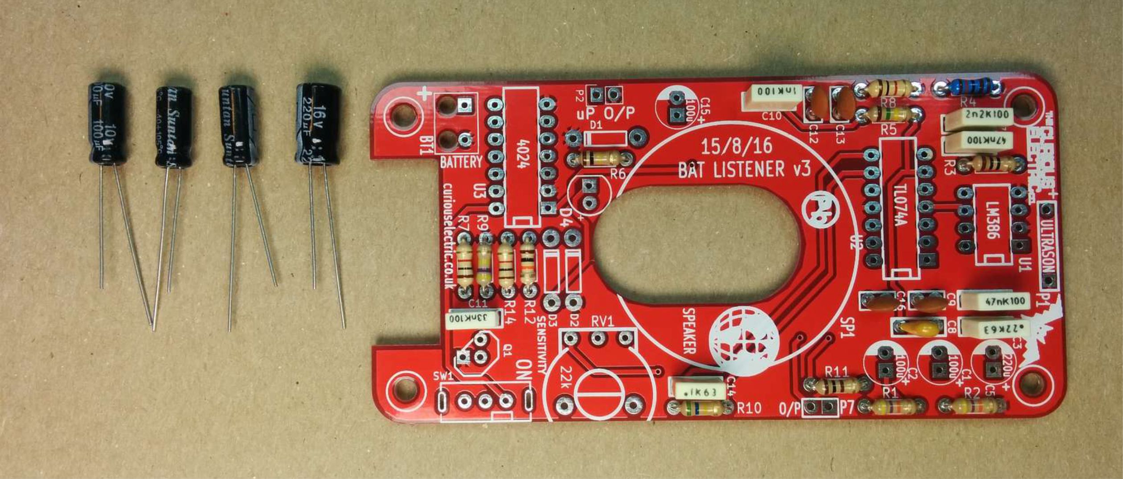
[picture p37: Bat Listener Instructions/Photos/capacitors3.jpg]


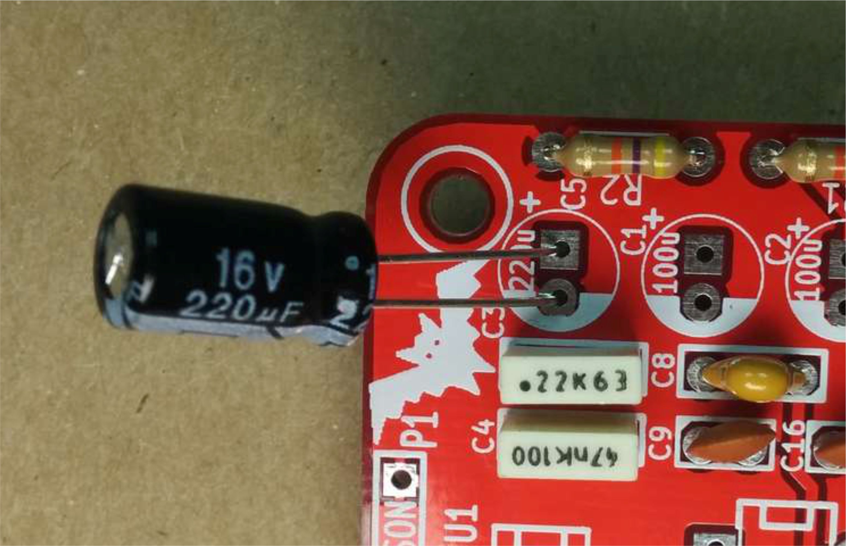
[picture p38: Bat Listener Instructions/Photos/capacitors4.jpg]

   
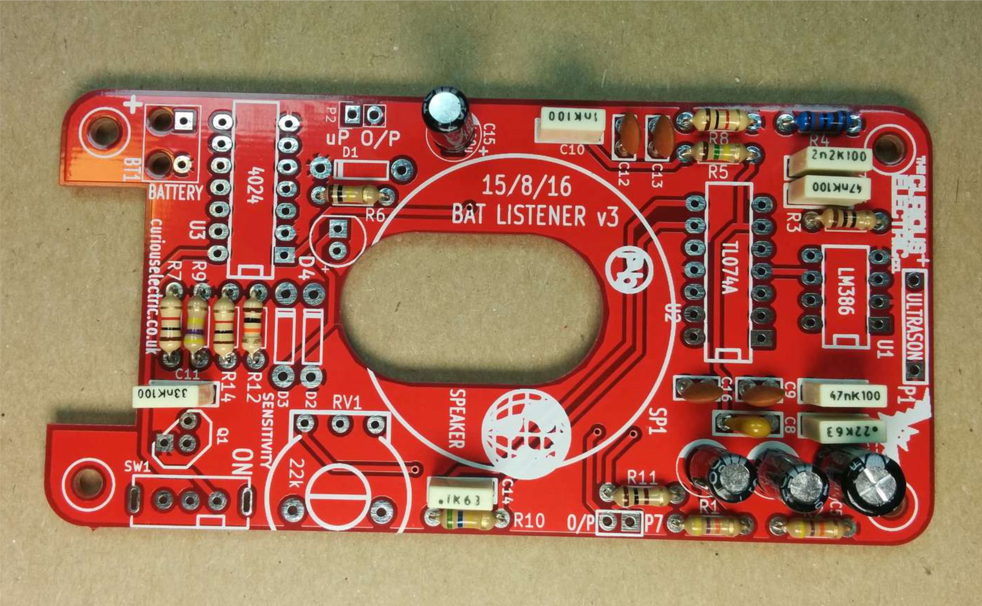
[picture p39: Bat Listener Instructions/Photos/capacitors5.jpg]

   
The capacitors are:

| Value | Identification | Reference |
|--- |--- |---|
| 0.1uF | Cream box with ".1J63" Markings | C1 |
| 22uF | Black cylinder with white stripe. "22uF" Marked | C2 |

First solder the non-polarised capacitors.
Orientation of these does not matter:

Next solder the polarised capacitors. Ensure correct orientation of these components. 
The negative lead is marked with a white strip. The positive lead is slightly longer than the negative. Align the positive lead with the + sign and the negative lead with the white PCB marking.

Step 3: Solder the diodes
-------------------------

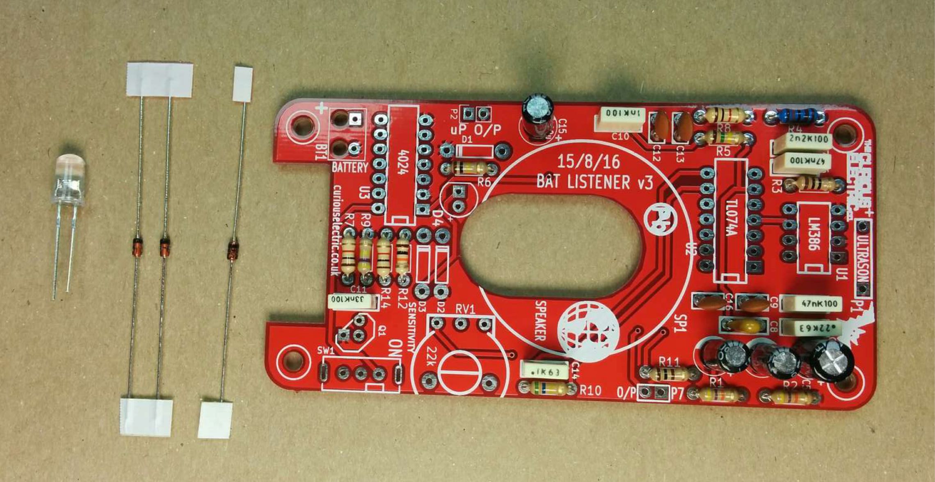
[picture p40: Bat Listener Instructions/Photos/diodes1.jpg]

   
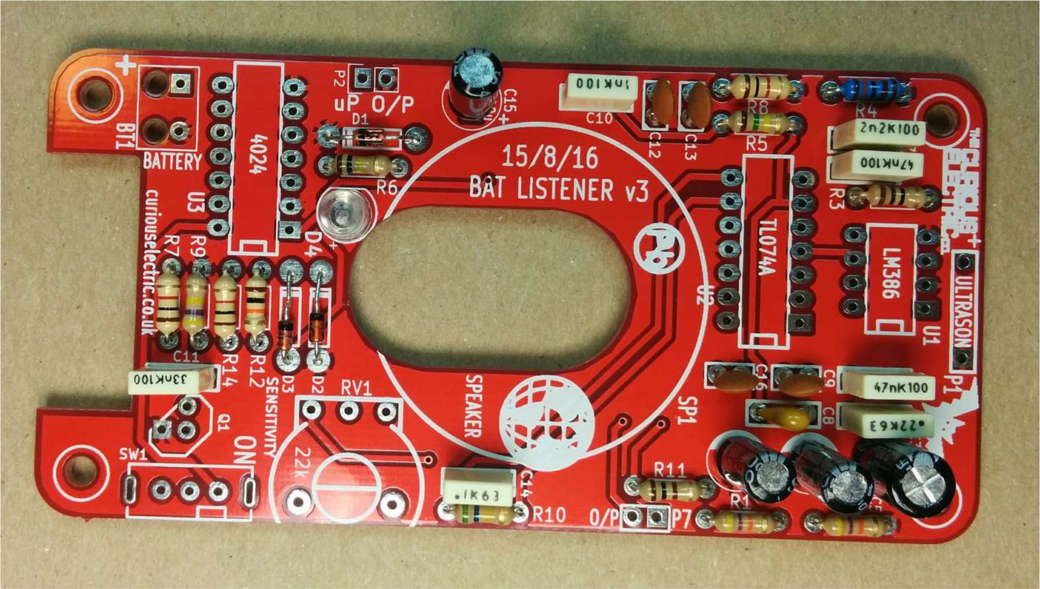
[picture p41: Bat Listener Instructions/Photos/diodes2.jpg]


There are 4 diodes to solder.
Ensure correct orientation for these components.

First solder the LED into D4.
The long lead is positive, so place that into the hole marked +. The negative side is slightly flat.

Then solder the 5.1V zener diode into D1. This diode is on its own and has very tiny marking of “5V1”. Ensure the black band aligns with the white band marked on the PCB.

The solder the remaining 2 diodes into D2 and D3. These have tiny markings saying “4148”. Ensure the black band aligns with the white band marked on the PCB.

Step 4: Solder the transistor
-----------------------------

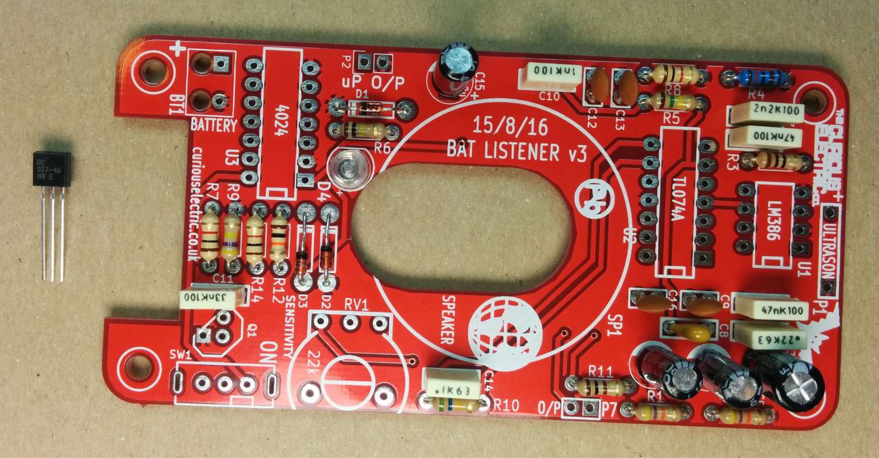
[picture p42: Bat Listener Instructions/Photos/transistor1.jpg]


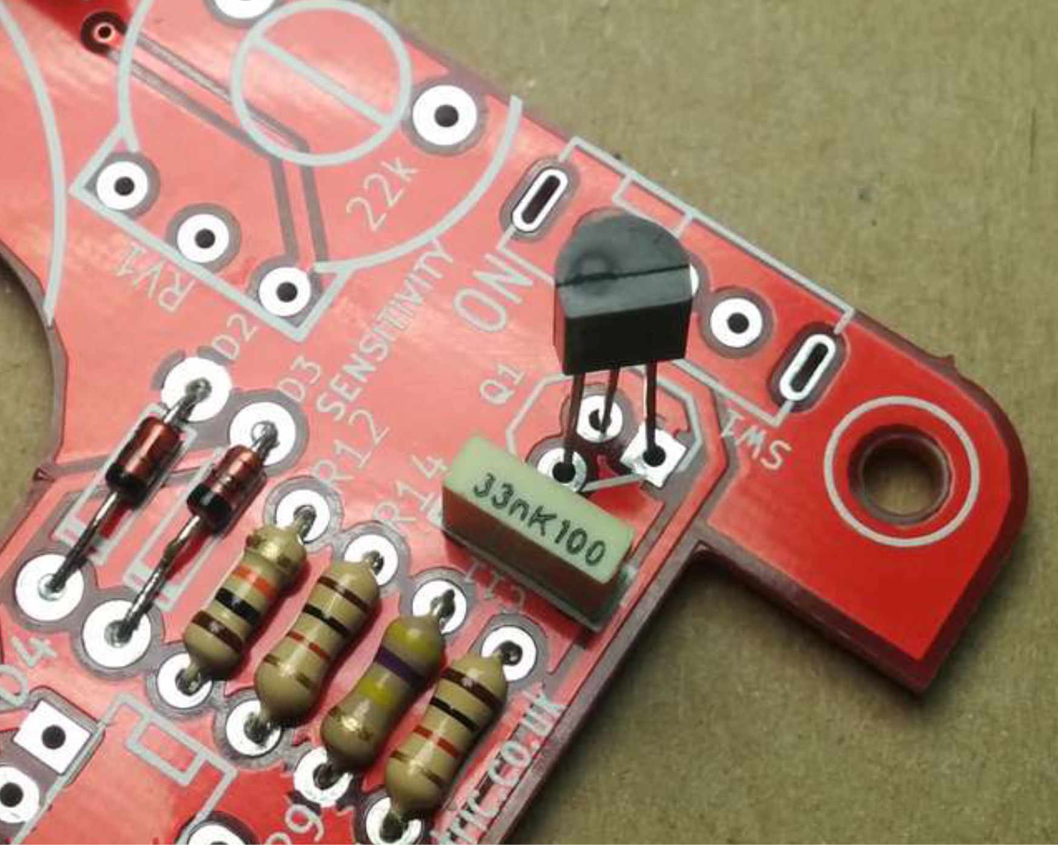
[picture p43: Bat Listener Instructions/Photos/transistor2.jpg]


There is just one transistor to solder, Q1, BC337.
Ensure the flat side of the transistor aligns with the PCB markings.

Step 5: Solder the IC holders
-----------------------------

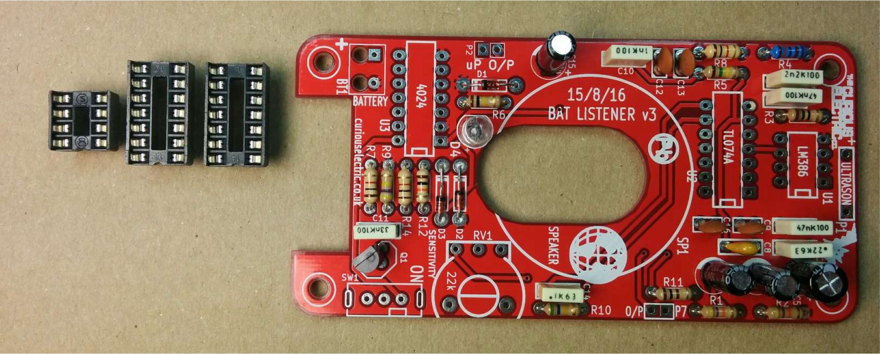
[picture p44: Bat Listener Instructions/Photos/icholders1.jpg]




There are two 14pin IC holders and one 8 pin IC holder. These fit into the areas marked U1, U2 and U3.

Ensure correct orientation!

Ensure the notch on the holder aligns with the notch shown on the PCB. 

Step 6: Solder Switch and Potentiometer
---------------------------------------





The switch fits into the holes marked SW1. The switch knob goes off the PCB.
Solder all metal tabs.

The potentiometer fits into the holes marked RV1. There are 5 pins to align and the pins might need slightly moving to ensure they align correctly.
Solder all metal tabs.

Step 7: Solder the ultrasonic receiver
--------------------------------------




   


The ultrasonic receiver has two pins, one is attached to the metal case of the unit, the other has a small ring around it.

The pin with the small ring around it is the +ve connection and this pin fits in the hole with the + symbol. The ground fits next to the indicator P1.

Carefully bend the legs to 90 degrees to the receiver is facing away from the PCB.

Step 8: Solder Speaker
----------------------







The speaker has a slightly unusual mounting method.

The speaker base fits through the large hole in the PCB and the speaker tabs alight with the PCB tabs.

Use an offcut of resistor lead and solder two small leads from the PCB (as shown).

Then pt the speaker in place and solder the small wires to the speaker.

This method holds the speaker in place, as well as being the electrical connection.

Step 9: Solder PP3 battery connector 
------------------------------------


   




Nearly there!

The PP3 battery clip as two wires: one positive (red) and one negative (black).

I usually put a knot in the cable for strain relief.

The cables then go through the larger holes and are fed back into the solder pads.

The red cable goes through the hole to the pad marked “+”.

Step 10: Insert ICs
-------------------





Now we need to insert the ICs into their holders.
Ensure the notches align with the notches on the IC holders and the PCB.

U1 is the LM386 (8 pin)
U2 is the TL074A (14 pin)
U3 is the 4024 (14 pin)

Step 11: Insert battery and test
--------------------------------

Add a PP3 9V battery to the battery clip. Switch the unit on.
You may hear a squeal from the device. Adjust potentiometer until you just do not hear any noise.

The red LED should also flash when the speaker clicks.

Use a reel of sticky tape to test. Slowly peel the tape off the reel and you should hear crackles from the speaker. This is picking up high frequency sound from the glue breaking. You can also test by pointing at a compact fluorescent light bulb. These switch at around 100kHz and hence give off ultrasonic noise.

Step 12: PCB is finished!
-------------------------

Have a nice cup of tea!

If you have designed your own enclosure then you can stop here.
If you have bought our kit with the enclosure then here are the instructions to fit the completed PCB into the laser cut enclosure. 

Enclosure Instructions:
=======================

Step 1: Push out laser-cut parts and peel off protective layer
--------------------------------------------------------------





Sometimes not all the small laser-cut pieces have been removed. These can be pushed out using the point of a screwdriver. Only slight force should be required.

There is a protective film on one side of the laser cut parts. This can be removed by peeling off the film.

Step 2: Screw down the PCB
--------------------------


   

   




The PCB is held onto the back plate using the M3 10mm screws and the hex spacers.

The back plate has the text facing to the back.

The screws fit through the back plate then through a small circular spacer ring and then through the PCB.

It is then held in place using the threaded hex spacer.

Do this for all four corners of the PCB.

Step 3: Add end spacers
-----------------------





To hold the end spacers in place we again use the 10mm screws and 2 of the hex spacers.

Put them through the back plate and slightly screw the hex spacer onto the screw.

Do not fully tighten this, as it will need to spin to be adjusted in the next step.

Step 4: Add battery holders
---------------------------





The battery holders are 6 spacers which holds one end of the battery, with the other end being held the notch in the PCB.
There are three types of spacer:
1 x narrow 3mm spacer (in white frosted plastic)
4 x wide 3mm spacers (with an “M” etched on them).
1 x narrow 2mm spacer in clear plastic.

These fit onto the hex spacers we just added.

First add the narrow 3mm piece.

Then the 4 wide 3mm pieces (marked “M”).

Put the battery into the enclosure. The PP3 battery clip fits within the wider section, with the cable able to come out of the side.

The final narrow 2mm space is put on top.





Step 5: Fit top cover
---------------------





The front cover is then put on with the text facing upwards.
Use the final 6 x 6mm M3 machine screws to hold the front cover in place.
These fasten into the threaded hex spacers.

Note: Some covers do not have the hole for the LED. The LED can be seen through the frosted plastic, so it is not needed.

Step 6: Finished!
-----------------



That is the unit finished!

The on/off switch and the potentiometer are accessible via the side of the unit.

You now have your own bat detector.

There are many things you can investigate including:

**Nature:** monitor bats, mice and rats

**Electrical:** Check the sound from switching power supplies and fluorescent lights

Circuit Overview
================

This kit is based upon a circuit [originally published by Elektor Electronics](http://www.elektor.com/magazines/2011/november/simple-bat-detector.1971945.lynkx)

It was originally developed as a workshop for [Nottingham Hackspace](www.nottinghack.co.uk)

Circuit Schematic
-----------------



Suppliers Information
=====================

We would like you to be happy with this kit. If you are not happy for any reason then please contact us and we will help to sort it out.

Please email **hello@curiouselectric.co.uk** with any questions or comments or please tweet us at **@curiouselectric**

If any parts are missing from your kit then please email **hello@curiouselectric.co.uk** with details and, if possible, where the kit was purchased.

More technical information can be found via **www.curiouselectric.co.uk**

The GITHUB repository for all these files is: **https://github.com/curiouselectric/soldersolar**

This kit has been designed and produced by:



..

   The Curious Electric Company
   
   hello@curiouselectric.co.uk
   
   www.curiouselectric.co.uk
   
   Hopkinson,
   
   21 Station Street,
   
   Nottingham,
   
   NG2 3AJ, UK

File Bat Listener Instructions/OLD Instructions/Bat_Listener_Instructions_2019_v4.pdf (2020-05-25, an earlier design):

## Bat Detector Kit

Date: | 13/10/2019 | Version: | 4.0 | By: | Matt Little


Build your own Bat Detector!

Bats use ultra-sonic pulses to navigate and to detect prey. These pulses are very high pitch (around 5 times the maximum frequency humans can hear).

This electronic circuit converts the high pitched sounds produced by bats to a human-audiable level.

It has a sensitivity control to adjust for different conditions.

It can also be used to listen to other high frequencies such as peeling sticky tape, compact fluorescent lights and power supplies.

This kit, although easy to build, requires quite a lot of soldering so will take in the region of 2-3 hours.

Parts included:; Ultrasonic receiver; LED; 5.1V Zener; 2 x 1N4148 Diodes; Speaker; PP3 battery clip; 13 x Resistors; 16 x Capacitors; Potentiometer; Transistor; PCB; Switch; holders; 3 x ICs

Item | Ref | Item | Ref
PP3 Batter Clip | BT1 | 47k Rtsistoe | R1, R2
100uf Capacitoe | C1, C2, C15 | 10 ohm Rtsistoe | R3
220nf Capacitoe | C3 | 1.3k Rtsistoe | R4
47nf Capacitoe | C4, C6 | 150k Rtsistoe | R5
220uf Capacitoe | C5 | 10k Rtsistoe | R6, R12
2.2nf Capacitoe | C7 | 1k Rtsistoe | R7, R8, R14
1.5nf Capacitoe | C8 | 470k Rtsistoe | R9
100pf Capacitoe | C9, C16 | 560k Rtsistoe | R10
1nf Capacitoe | C10 | 100 ohm Rtsistoe | R11
33nf Capacitoe | C11 | 20k Pottntomttte | RV1
470pf Capacitoe | C12, C13 | 40mm Loudsptakte | SP1
100nf Capacitoe | C14 | Switch | SW1
3.3V Ztnte Diodt | D1 | LM386 Audio Amplifte I C | U1

1N4148 small signal Diodt | D2,D3 | TL074 Quad-compaeatoe I C | U2

5mm Rtd LED | D4 | 4024 Countte I C | U3

Ulteasonic Rtctivte | P1
B C337 Teansistoe | Q1
Enclosuet
Feont | x1 | 3mm P CB spacte eings | x4
Back | x1 | M3 Htx spactes 9mm | x6
2mm cltae plastc spacte (maektd '6' | x1 | M3 6mm machint scetws | x4
3mm feosttd plastc spacte (numbtetd '1' - '5' | X5 | M3 12mm machint scetws | x8

PCB Instructions:

Step: 1 | Solder resistors
Value | Ref | Colour
47k | R1, R2 | Ytllow, Violtt, Oeangt, Gold


10 | R3 | Beown, Black, Black, Gold
1.3k | R4 | Beown, Oeangt, Black, Beown, Beown (This resistor is blue
150k | R5 | Beown, Gettn, Ytllow, Gold
10k | R6 | Beown, Black, Oeangt, Gold
1k | R7,R8,R14 | Beown, Black, Rtd, Gold
470k | R9 | Ytllow, Violtt, Ytllow, gold
560k | R10 | Gettn, Blut, Ytllow, Gold
100 | R11 | Beown, Black, Beown, Gold
10k | R12 | Beown, Black, Oeangt, Gold

Insert and solder the resistors. Polarity does not matter for resistors. Ensure they are soldered flat close to the PCB.

Use a multimeter or colour code chart to ensure correct resistor values.

Step: 2 | Solder capacitors
First solder the non-polarised capacitors. Orientation of these does not matter:


Value | Ref | Marking
220nf | C3 | .22K63 (cetam box
47nf | C4, C6 | 47nK100 (cetam box
2.2nf | C7 | 2n2K100 (cetam box
1.5nf | C8 | 152 (beown blob
100pf | C9, C16 | 101 (beown disk
1nf | C10 | 1nK100 (cetam box
33nf | C11 | 33nK100 (cetam box
470pf | C12, C13 | 471 (beown disk
100nf | C14 | .1K63 oe .1J63 (cetam box

Note: You may need a magnifying glass for reading the text on these capacitors.


Next solder the polarised capacitors. Ensure correct orientation of these components.
The negative lead is marked with a white strip. The positive lead is slightly longer than the negative. Align the positive lead with the + sign and the negative lead with the white PCB marking.


Value | Ref | Marking
100uf Capacitoe | C1, C2, C15 | 10V 100uf
220uf Capacitoe | C5 | 16V 220uf


Step: 3 Solder diodes
There are 4 diodes to solder. Ensure correct orientation for these components.

First solder the LED into D4. The long lead is positive, so place that into the hole marked +. The negative side is slightly flat.

Then solder the 5.1 V zener diode into D1. This diode is on it’s own and has very tiny marking of “5V1”. Ensure the black band aligns with the white band marked on the PCB.

Then solder the remaining 2 diodes into D2 and D3. These have tiny markings saying
“4148”. Ensure the black band aligns with the white band marked on the PCB.

Step: 4 Solder transistor
There is just one transistor to solder, Q1, BC337.
Ensure the flat side of the transistor aligns with the PCB markings.


Step: 5 Solder IC holders
There are two 14 pin IC
holders and one 8 pin IC
holder. These fit into the areas marked U1, U2 and U3.

Ensure correct orientation!

Ensure the notch on the
holder aligns with the notch shown on the PCB.

Step: 6 Solder Switch and Potentiometer The switch fits into the holes
marked SW1. The switch
knob goes off the PCB.
Solder all metal tabs.

The potentiometer fits into the holes marked RV1.
There are 5 pins to align and the pins might need slightly moving to ensure they align correctly.

Solder all metal tabs.

Step: 7 | Solder the ultrasonic receiver
The ultrasonic receiver has two pins, one is attached to the metal case of the unit, the other has a small ring around it. The pin with the small ring around it is the +ve connection and this pin fits in the hole with the + symbol. The ground fits next to the indicator P1. Carefully bend the legs to 90 degrees to the receiver is facing away from the PCB.

Step: 8 Solder Speaker


The speaker has a slightly unusual mounting method.


The speaker base fits through the large hole in the PCB and the speaker tabs align with the PCB tabs.

Use an off-cut of resistor lead and solder two small leads from the PCB (as shown). Carefully bend the legs to 90 degrees before soldering in position facing away from the PCB.

Then put the speaker in place and solder the small wires to the speaker.


This method holds the speaker in place, as well as being the electrical connection.


Step: 9 Solder PP3 battery connector Nearly there!
The PP3 battery clip as
two wires: one positive
(red) and one negative
(black).

I usually put a knot in
the cable for strain
relief.

The cables then go
through the larger holes
from the underside and
are fed back into the
solder pads.

The red cable goes
through the hole to the
pad marked “+”.
Step: 10 | Insert ICs
| Now we need to insert the ICs into their holders. Ensure the notches align with the notches on the IC holders and the PCB. U1 is the LM386 (8 pin) U2 is the TL074 (14 pin) U3 is the 4024 (14 pin)

Step: 11 | Insert battery and test
Add a PP3 9V battery to the battery clip. Switch the unit on. You may hear a squeal from the device. Adjust the potentiometer until you just do not hear any noise. The red LED should also flash when the speaker clicks. Use a reel of sticky tape to test. Slowly peel the tape off the reel and you should hear crackles from the speaker. This is picking up high frequency sound from the glue breaking. You can also test by pointing at a compact fluorescent light bulb. These switch at around 100 kHz and hence give off ultrasonic noise.
Step: 12 | PCB is finished!


| Have a nice cup of tea.

Enclosure Instructions:

Step: 1 Push out laser-cut parts and peel off protective layer Sometimes not all the small laser-cut pieces have been removed.
These can be pushed out using the
point of a screwdriver. Only slight force should be required.


There is a protective film on one side of the laser cut parts. This can be removed by peeling off the film.


Step: 2 Screw down the PCB The PCB is held onto the back plate using 4 of the M3 12mm screws and the hex spacers.


The back plate has the text facing to the back.

The screws fit through the back plate then through a small circular spacer ring and then through the PCB.

It is then held in place using the threaded hex spacer.

Do this for all four corners of the PCB.

Step: 3 Add end spacers
To hold the end spacers in place we again use the
12mm screws and 2 of the
hex spacers.


Put them through the back
plate and slightly screw the hex spacer onto the screw.


Do not fully tighten this, as it will need to spin to be
adjusted in the next step.

Step: 4 Add battery holders

The battery holders are 6 spacers which holds one end of the battery, with the other end being held the notch in the PCB. There are three types of spacer: 1 x narrow 3mm spacer (in white frosted plastic, marked “1”) 4 x wide 3mm spacers (marked “2”, ”3”, ”4” & “5” ). 1 x narrow 2mm spacer in clear plastic (marked “6”).; These fit onto the hex spacers we just added.

First add the narrow 3mm piece(marked “1”).

Then the 4 wide 3mm pieces (marked “2”, ”3”, ”4” & “5”).

Put the battery into the enclosure. The PP3 battery clip fits within the wider section, with the cable able to come out of the side.

The final narrow 2mm spacer (marked “6”) is put on top.


Step: 5 Fit top cover
The front cover is then put on with the text facing upwards. Use the 4 x 6mm M3 machine screws to hold the front cover in place to the PCB holes and the final 2 x 12mm M3 machine
screws to hold the end spacers in place.
These fasten into the threaded hex spacers.


Note: Some covers do not have the hole for the LED. The LED can be seen through the frosted plastic, so it is not needed.

Step: 6 Finished!
That is the unit finished!

The on/off switch and the potentiometer are accessible via the side of the unit.

You now have your own bat detector.

There are many things you can investigate including:

Nature: monitor bats, mice and rats

Electrical: Check the sound from switching power supplies and fluorescent lights

Please note: This unit is NOT waterproof. Do NOT leave outside if it will get wet.

Contact details:
We would like you to be happy with this kit. If you are not happy for any reason then please contact us and we will help to sort it out.

Please email hello@curiouselectric.co.uk with any questions or comments.
Please tweet us at @curiouselectric

If any parts are missing from your kit then please email hello@curiouselectric.co.uk with details and, if possible, where the kit was purchased.

More technical information can be found via www.curiouselectric.co.uk

This kit has been designed and produced by:

## The Curious Electric Company

hello@curiouselectric.co.uk www.curiouselectric.co.uk
Unit 23, Block D, Hartley Business Centre, Haydn Rd, Nottingham, NG5 1DG, UK

History

This kit is based upon a circuit originally published by Elektor Electronics: http://www.elektor.com/magazines/2011/november/simple-bat-detector.1971945.lynkx

and was originally developed as a workshop for Nottingham Hackspace: www.nottinghack.co.uk

Circuit Schematic


Resistor Colour Codes

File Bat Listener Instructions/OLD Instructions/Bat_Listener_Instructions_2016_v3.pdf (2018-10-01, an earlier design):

## Bat Detector Kit

Date: | 16/9/2018 | Version: | 2.0 | By: | Matt Little


Build your own Bat Detector!

Bats use ultra-sonic pulses to navigate and to detect prey. These pulses are very high pitch (around 5 times the maximum frequency humans can hear).

This electronic circuit converts the high pitched sounds produced by bats to a human-audiable level.

It has a sensitivity control to adjust for different conditions.

It can also be used to listen to other high frequencies such as peeling sticky tape, compact fluorescent lights and power supplies.

This kit, although easy to build, requires quite a lot of soldering so will take in the region of 2-3 hours.

Parts included:; Ultrasonic receiver; LED; 5.1V Zener; 2 x 1N4148 Diodes; Speaker; PP3 battery clip; 13 x Resistors; 16 x Capacitors; Potentiometer; Transistor; PCB; Switch; holders; 3 x ICs

Item | Ref | Item | Ref
PP3 Batter Clip | BT1 | 47k Rtsistoe | R1, R2
100uf Capacitoe | C1, C2, C15 | 10 ohm Rtsistoe | R3
220nf Capacitoe | C3 | 1.3k Rtsistoe | R4
47nf Capacitoe | C4, C6 | 150k Rtsistoe | R5
220uf Capacitoe | C5 | 10k Rtsistoe | R6, R12
2.2nf Capacitoe | C7 | 1k Rtsistoe | R7, R8, R14
1.5nf Capacitoe | C8 | 470k Rtsistoe | R9
100pf Capacitoe | C9, C16 | 560k Rtsistoe | R10
1nf Capacitoe | C10 | 100 ohm Rtsistoe | R11
33nf Capacitoe | C11 | 20k Pottntomttte | RV1
470pf Capacitoe | C12, C13 | 40mm Loudsptakte | SP1
100nf Capacitoe | C14 | Switch | SW1
3.3V Ztnte Diodt | D1 | LM386 Audio Amplifte I C | U1

1N4148 small signal Diodt | D2,D3 | TL074 Quad-compaeatoe I C | U2

5mm Rtd LED | D4 | 4024 Countte I C | U3

Ulteasonic Rtctivte | P1
B C337 Teansistoe | Q1
Enclosuet
Feont | x1 | 3mm P CB spacte eings | x4
Back | x1 | M3 Htx spactes 9mm | x6
2mm cltae plastc spacte (maektd '6' | x1 | M3 6mm machint scetws | x4
3mm feosttd plastc spacte (numbtetd '1' - '5' | X5 | M3 12mm machint scetws | x8

Tools required:

PCB Instructions:

Step: 1 | Solder resistors
Value | Ref | Colour
47k | R1, R2 | Ytllow, Violtt, Oeangt, Gold


10 | R3 | Beown, Black, Black, Gold
1.3k | R4 | Beown, Oeangt, Black, Beown, Beown (This resistor is blue
150k | R5 | Beown, Gettn, Ytllow, Gold
10k | R6 | Beown, Black, Oeangt, Gold
1k | R7,R8,R14 | Beown, Black, Rtd, Gold
470k | R9 | Ytllow, Violtt, Ytllow, gold
560k | R10 | Gettn, Blut, Ytllow, Gold
100 | R11 | Beown, Black, Beown, Gold
10k | R12 | Beown, Black, Oeangt, Gold

Insert and solder the resistors. Polarity does not matter for resistors. Ensure they are soldered flat close to the PCB.

Use a multimeter or colour code chart to ensure correct resistor values.

Step: 2 | Solder capacitors
First solder the non-polarised capacitors. Orientation of these does not matter:


Value | Ref | Marking
220nf | C3 | .22K63 (cetam box
47nf | C4, C6 | 47nK100 (cetam box
2.2nf | C7 | 2n2K100 (cetam box
1.5nf | C8 | 152 (beown blob
100pf | C9, C16 | 101 (beown disk
1nf | C10 | 1nK100 (cetam box
33nf | C11 | 33nK100 (cetam box
470pf | C12, C13 | 471 (beown disk
100nf | C14 | .1K63 oe .1J63 (cetam box

Note: You may need a magnifying glass for reading the text on these capacitors.


Next solder the polarised capacitors. Ensure correct orientation of these components.
The negative lead is marked with a white strip. The positive lead is slightly longer than the negative. Align the positive lead with the + sign and the negative lead with the white PCB marking.
Value | Ref | Marking
100uf Capacitoe | C1, C2, C15 | 10V 100uf
220uf Capacitoe | C5 | 16V 220uf


Step: 3 Solder diodes
There are 4 diodes to solder. Ensure correct orientation for these components.

First solder the LED into D4. The long lead is positive, so place that into the hole marked +. The negative side is slightly flat.

Then solder the 5.1 V zener diode into D1. This diode is on it’s own and has very tiny marking of “5V1”. Ensure the black band aligns with the white band marked on the PCB.

Then solder the remaining 2 diodes into D2 and D3. These have tiny markings saying
“4148”. Ensure the black band aligns with the white band marked on the PCB.

Step: 4 Solder transistor
There is just one transistor to solder, Q1, BC337.
Ensure the flat side of the transistor aligns with the PCB markings.


Step: 5 Solder IC holders
There are two 14 pin IC
holders and one 8 pin IC
holder. These fit into the areas marked U1, U2 and U3.

Ensure correct orientation!

Ensure the notch on the
holder aligns with the notch shown on the PCB.

Step: 6 Solder Switch and Potentiometer The switch fits into the holes
marked SW1. The switch
knob goes off the PCB.
Solder all metal tabs.

The potentiometer fits into the holes marked RV1.
There are 5 pins to align and the pins might need slightly moving to ensure they align correctly.

Solder all metal tabs.

Step: 7 | Solder the ultrasonic receiver
The ultrasonic receiver has two pins, one is attached to the metal case of the unit, the other has a small ring around it. The pin with the small ring around it is the +ve connection and this pin fits in the hole with the + symbol. The ground fits next to the indicator P1. Carefully bend the legs to 90 degrees to the receiver is facing away from the PCB.

Step: 8 Solder Speaker


The speaker has a slightly unusual mounting method.


The speaker base fits through the large hole in the PCB and the speaker tabs align with the PCB tabs.

Use an off-cut of resistor lead and solder two small leads from the PCB (as shown). Carefully bend the legs to 90 degrees before soldering in position facing away from the PCB.


Then put the speaker in place and solder the small wires to the speaker.


This method holds the speaker in place, as well as being the electrical connection.


Step: 9 Solder PP3 battery connector Nearly there!
The PP3 battery clip as
two wires: one positive
(red) and one negative
(black).

I usually put a knot in
the cable for strain
relief.

The cables then go
through the larger holes
from the underside and
are fed back into the
solder pads.

The red cable goes
through the hole to the
pad marked “+”.
Step: 10 | Insert ICs
| Now we need to insert the ICs into their holders. Ensure the notches align with the notches on the IC holders and the PCB. U1 is the LM386 (8 pin) U2 is the TL074 (14 pin) U3 is the 4024 (14 pin)

Step: 11 | Insert battery and test
Add a PP3 9V battery to the battery clip. Switch the unit on. You may hear a squeal from the device. Adjust the potentiometer until you just do not hear any noise. The red LED should also flash when the speaker clicks. Use a reel of sticky tape to test. Slowly peel the tape off the reel and you should hear crackles from the speaker. This is picking up high frequency sound from the glue breaking. You can also test by pointing at a compact fluorescent light bulb. These switch at around 100 kHz and hence give off ultrasonic noise.
Step: 12 | PCB is finished!


| Have a nice cup of tea.

Enclosure Instructions:

Step: 1 Push out laser-cut parts and peel off protective layer Sometimes not all the small laser-cut pieces have been removed.
These can be pushed out using the
point of a screwdriver. Only slight force should be required.


There is a protective film on one side of the laser cut parts. This can be removed by peeling off the film.


Step: 2 Screw down the PCB The PCB is held onto the back plate using 4 of the M3 12mm screws and the hex spacers.


The back plate has the text facing to the back.

The screws fit through the back plate then through a small circular spacer ring and then through the PCB.

It is then held in place using the threaded hex spacer.

Do this for all four corners of the PCB.

Step: 3 Add end spacers
To hold the end spacers in place we again use the
12mm screws and 2 of the
hex spacers.


Put them through the back
plate and slightly screw the hex spacer onto the screw.

Do not fully tighten this, as it will need to spin to be
adjusted in the next step.

Step: 4 Add battery holders

The battery holders are 6 spacers which holds one end of the battery, with the other end being held the notch in the PCB. There are three types of spacer: 1 x narrow 3mm spacer (in white frosted plastic, marked “1”) 4 x wide 3mm spacers (marked “2”, ”3”, ”4” & “5” ). 1 x narrow 2mm spacer in clear plastic (marked “6”).; These fit onto the hex spacers we just added.

First add the narrow 3mm piece(marked “1”).

Then the 4 wide 3mm pieces (marked “2”, ”3”, ”4” & “5”).

Put the battery into the enclosure. The PP3 battery clip fits within the wider section, with the cable able to come out of the side.

The final narrow 2mm spacer (marked “6”) is put on top.


Step: 5 Fit top cover
The front cover is then put on with the text facing upwards. Use the 4 x 6mm M3 machine screws to hold the front cover in place to the PCB holes and the final 2 x 12mm M3 machine
screws to hold the end spacers in place.
These fasten into the threaded hex spacers.


Note: Some covers do not have the hole for the LED. The LED can be seen through the frosted plastic, so it is not needed.

Step: 6 Finished!
That is the unit finished!

The on/off switch and the potentiometer are accessible via the side of the unit.

You now have your own bat detector.

There are many things you can investigate including:

Nature: monitor bats, mice and rats

Electrical: Check the sound from switching power supplies and fluorescent lights

Please note: This unit is NOT waterproof. Do NOT leave outside if it will get wet.

Contact details:
We would like you to be happy with this kit. If you are not happy for any reason then please contact us and we will help to sort it out.

Please email hello@curiouselectric.co.uk with any questions or comments.
Please tweet us at @curiouselectric

If any parts are missing from your kit then please email hello@curiouselectric.co.uk with details and, if possible, where the kit was purchased.

More technical information can be found via www.curiouselectric.co.uk

This kit has been designed and produced by:

## The Curious Electric Company

hello@curiouselectric.co.uk www.curiouselectric.co.uk
Hopkinson, 21 Station Street, Nottingham, NG2 3AJ, UK

History

This kit is based upon a circuit originally published by Elektor Electronics: http://www.elektor.com/magazines/2011/november/simple-bat-detector.1971945.lynkx

and was originally developed as a workshop for Nottingham Hackspace: www.nottinghack.co.uk

Circuit Schematic


Resistor Colour Codes

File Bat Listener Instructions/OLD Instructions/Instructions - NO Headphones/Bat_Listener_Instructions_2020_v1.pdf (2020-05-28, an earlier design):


Parts included:

Ultrasonic receiver | LED | 5.1 V Zener

### 2 x 1N4148

Diodes
Speaker

PP3 battery
clip

### 13 x

Resistors

### 16 x

Capacitors

Potentiometer

Transistor

PCB | Switch | 3 x IC holders

### 3 x ICs


Item | Ref | Item | Ref
PP3 Baery Clip | BT1 | 47k Resistor | R1, R2
100uf Capacitor | C1, C2, C15 | 10 ohm Resistor | R3
220nf Capacitor | C3 | 1.3k Resistor | R4
47nf Capacitor | C4, C6 | 150k Resistor | R5
220uf Capacitor | C5 | 10k Resistor | R6, R12
2.2nf Capacitor | C7 | 1k Resistor | R7, R8, R14
1.5nf Capacitor | C8 | 470k Resistor | R9
100pf Capacitor | C9, C16 | 560k Resistor | R10
1nf Capacitor | C10 | 100 ohm Resistor | R11
33nf Capacitor | C11 | 20k Potenometer | RV1
470pf Capacitor | C12,C13 | 40mm Loudspeaker | SP1
100nf Capacitor | C14 | Switch | SW1
5.1V Zener Diode | D1 | LM386 Audio Amplifier IC | U1

1N4148 small signal Diode | D2,D3 | TL074 Quad-comparator IC | U2

5mm Red LED | D4 | 4024 Counter IC | U3

Ultrasonic Receiver | P1
BC337 Transistor | Q1
Enclosure
Front | x1 | 3mm PCB spacer rings | x4
Back | x1 | M3 Hex spacers 9mm | x6
2mm clear plasc spacer (marked '6') | x1 | M3 6mm machine screws | x4
3mm frosted plasc spacer (numbered '1' - '5') | X5 | M3 12mm machine screws | x8

Tools required:


PCB Instructions:

Step: 1 | Solder resistors
Value | Ref | Colour
47k | R1, R2 | Yellow, Violet, Orange, Gold


10 | R3 | Brown, Black, Black, Gold
1.3k | R4 | Brown, Orange, Black, Brown, Brown (This resistor is blue)
150k | R5 | Brown, Green, Yellow, Gold
10k | R6 | Brown, Black, Orange, Gold
1k | R7,R8,R14 | Brown, Black, Red, Gold
470k | R9 | Yellow, Violet, Yellow, gold


560k | R10 | Green, Blue, Yellow, Gold
100 | R11 | Brown, Black, Brown, Gold
10k | R12 | Brown, Black, Orange, Gold

Insert and solder the resistors. Polarity does not matter for resistors. Ensure they are soldered flat close to the PCB.

Use a multimeter or colour code chart to ensure correct resistor values.

Step: 2 | Solder capacitors
First solder the non-polarised capacitors. Orientation of these does not matter:


Value | Ref | Marking
220nf | C3 | .22K63 (cream box)
47nf | C4, C6 | 47nK100 (cream box)
2.2nf | C7 | 2n2K100 (cream box)
1.5nf | C8 | 152 (brown blob)
100pf | C9, C16 | 101 (brown disk)
1nf | C10 | 1nK100 (cream box)
33nf | C11 | 33nK100 (cream box)
470pf | C12,C13 | 471 (brown disk)
100nf | C14 | .1K63 or .1J63 (cream box)

Note: You may need a magnifying glass for reading the text on these capacitors.

Next solder the polarised capacitors. Ensure correct orientation of these components.
The negative lead is marked with a white strip. The positive lead is slightly longer than the negative. Align the positive lead with the + sign and the negative lead with the white PCB marking.


Value | Ref | Marking
100uf Capacitor | C1, C2, C15 | 10V 100uf
220uf Capacitor | C5 | 16V 220uf


Step: 3 Solder diodes
There are 4 diodes to solder. Ensure correct orientation for these components.

First solder the LED into D4. The long lead is positive, so place that into the hole marked +. The negative side is slightly flat.

Then solder the 5.1 V zener diode into D1. This diode is on it’s own and has very tiny marking of “5V1”. Ensure the black band aligns with the white band marked on the PCB.

Then solder the remaining 2 diodes into D2 and D3. These have tiny markings saying
“4148”. Ensure the black band aligns with the white band marked on the PCB.

Step: 4 Solder transistor
There is just one transistor to solder, Q1, BC337.
Ensure the flat side of the transistor aligns with the PCB markings.


Step: 5 Solder IC holders
There are two 14 pin IC
holders and one 8 pin IC
holder. These fit into the areas marked U1, U2 and U3.

Ensure correct orientation!

Ensure the notch on the
holder aligns with the notch shown on the PCB.

Step: 6 Solder Switch and Potentiometer The switch fits into the holes
marked SW1. The switch
knob goes off the PCB.
Solder all metal tabs.

The potentiometer fits into the holes marked RV1.
There are 5 pins to align and the pins might need slightly moving to ensure they align correctly.

Solder all metal tabs.

Step: 7 | Solder the ultrasonic receiver
The ultrasonic receiver has two pins, one is attached to the metal case of the unit, the other has a small ring around it. The pin with the small ring around it is the +ve connection and this pin fits in the hole with the + symbol. The ground fits next to the indicator P1. Carefully bend the legs to 90 degrees to the receiver is facing away from the PCB.

Step: 8 Solder Speaker


The speaker has a slightly unusual mounting method.


The speaker base fits through the large hole in the PCB and the speaker tabs align with the PCB tabs.

Use an off-cut of resistor lead and solder two small leads from the PCB (as shown). Carefully bend the legs to 90 degrees before soldering in position facing away from the PCB.


Then put the speaker in place and solder the small wires to the speaker.


This method holds the speaker in place, as well as being the electrical connection.


Step: 9 Solder PP3 battery connector Nearly there!
The PP3 battery clip as
two wires: one positive
(red) and one negative
(black).

I usually put a knot in
the cable for strain
relief.

The cables then go
through the larger holes
from the underside and
are fed back into the
solder pads.

The red cable goes
through the hole to the
pad marked “+”.
Step: 10 | Insert ICs
| Now we need to insert the ICs into their holders. Ensure the notches align with the notches on the IC holders and the PCB. U1 is the LM386 (8 pin) U2 is the TL074 (14 pin) U3 is the 4024 (14 pin)

Step: 11 | Insert battery and test
Add a PP3 9V battery to the battery clip. Switch the unit on. You may hear a squeal from the device. Adjust the potentiometer until you just do not hear any noise. The red LED should also flash when the speaker clicks. Use a reel of sticky tape to test. Slowly peel the tape off the reel and you should hear crackles from the speaker. This is picking up high frequency sound from the glue breaking. You can also test by pointing at a compact fluorescent light bulb. These switch at around 100 kHz and hence give off ultrasonic noise.
Step: 12 | PCB is finished!
| Have a nice cup of tea.

Enclosure Instructions:

Step: 1 Push out laser-cut parts and peel off protective layer Sometimes not all the small laser-cut pieces have been removed.
These can be pushed out using the
point of a screwdriver. Only slight force should be required.


There is a protective film on one side of the laser cut parts. This can be removed by peeling off the film.


Step: 2 Screw down the PCB The PCB is held onto the back plate using 4 of the M3 12mm screws and the hex spacers.


The back plate has the text facing to the back.

The screws fit through the back plate then through a small circular spacer ring and then through the PCB.

It is then held in place using the threaded hex spacer.

Do this for all four corners of the PCB.

Step: 3 Add end spacers
To hold the end spacers in place we again use the
12mm screws and 2 of the
hex spacers.


Put them through the back
plate and slightly screw the hex spacer onto the screw.


Do not fully tighten this, as it will need to spin to be
adjusted in the next step.

Step: 4 Add battery holders

The battery holders are 6 spacers which holds one end of the battery, with the other end being held the notch in the PCB. There are three types of spacer: 1 x narrow 3mm spacer (in white frosted plastic, marked “1”) 4 x wide 3mm spacers (marked “2”, ”3”, ”4” & “5” ). 1 x narrow 2mm spacer in clear plastic (marked “6”).; These fit onto the hex spacers we just added.

First add the narrow 3mm piece(marked “1”).

Then the 4 wide 3mm pieces (marked “2”, ”3”, ”4” & “5”).

Put the battery into the enclosure. The PP3 battery clip fits within the wider section, with the cable able to come out of the side.

The final narrow 2mm spacer (marked “6”) is put on top.


Step: 5 Fit top cover
The front cover is then put on with the text facing upwards. Use the 4 x 6mm M3 machine screws to hold the front cover in place to the PCB holes and the final 2 x 12mm M3 machine
screws to hold the end spacers in place.
These fasten into the threaded hex spacers.


Note: Some covers do not have the hole for the LED. The LED can be seen through the frosted plastic, so it is not needed.

Step: 6 Finished!
That is the unit finished!

The on/off switch and the potentiometer are accessible via the side of the unit.

You now have your own bat detector.

There are many things you can investigate including:

Nature: monitor bats, mice and rats

Electrical: Check the sound from switching power supplies and fluorescent lights

Please note: This unit is NOT waterproof. Do NOT leave outside if it will get wet.

Contact details:
We would like you to be happy with this kit. If you are not happy for any reason then please contact us and we will help to sort it out.

Please email hello@curiouselectric.co.uk with any questions or comments.
Please tweet us at @curiouselectric

If any parts are missing from your kit then please email hello@curiouselectric.co.uk with details and, if possible, where the kit was purchased.

More technical information can be found via www.curiouselectric.co.uk

This kit has been designed and produced by:

### The Curious Electric Company

hello@curiouselectric.co.uk www.curiouselectric.co.uk
Unit 23, Block D, Hartley Business Centre, Haydn Rd, Nottingham, NG5 1DG, UK

History

This kit is based upon a circuit originally published by Elektor Electronics: http://www.elektor.com/magazines/2011/november/simple-bat-detector.1971945.lynkx

and was originally developed as a workshop for Nottingham Hackspace: www.nottinghack.co.uk

Circuit Schematic


Resistor Colour Codes

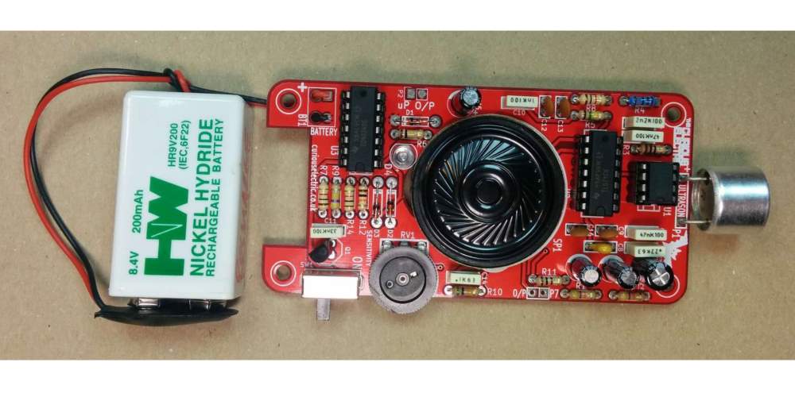
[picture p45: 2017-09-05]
Bat Listener Instructions/Photos/ics2_1000x500.jpg

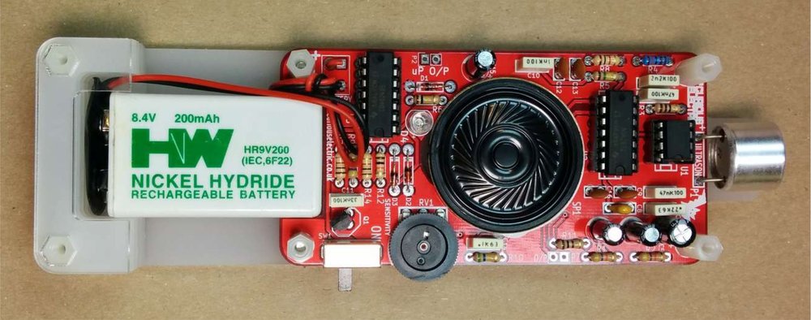
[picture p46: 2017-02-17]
Bat Listener Instructions/Photos/enclosure12_web.jpg

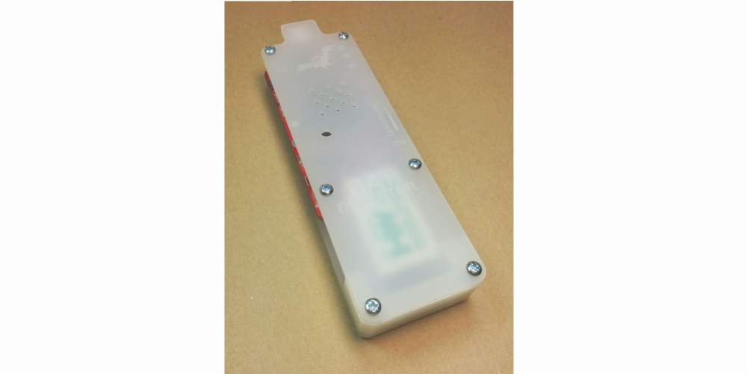
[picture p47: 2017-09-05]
Bat Listener Instructions/Photos/finished1_10000x500.jpg

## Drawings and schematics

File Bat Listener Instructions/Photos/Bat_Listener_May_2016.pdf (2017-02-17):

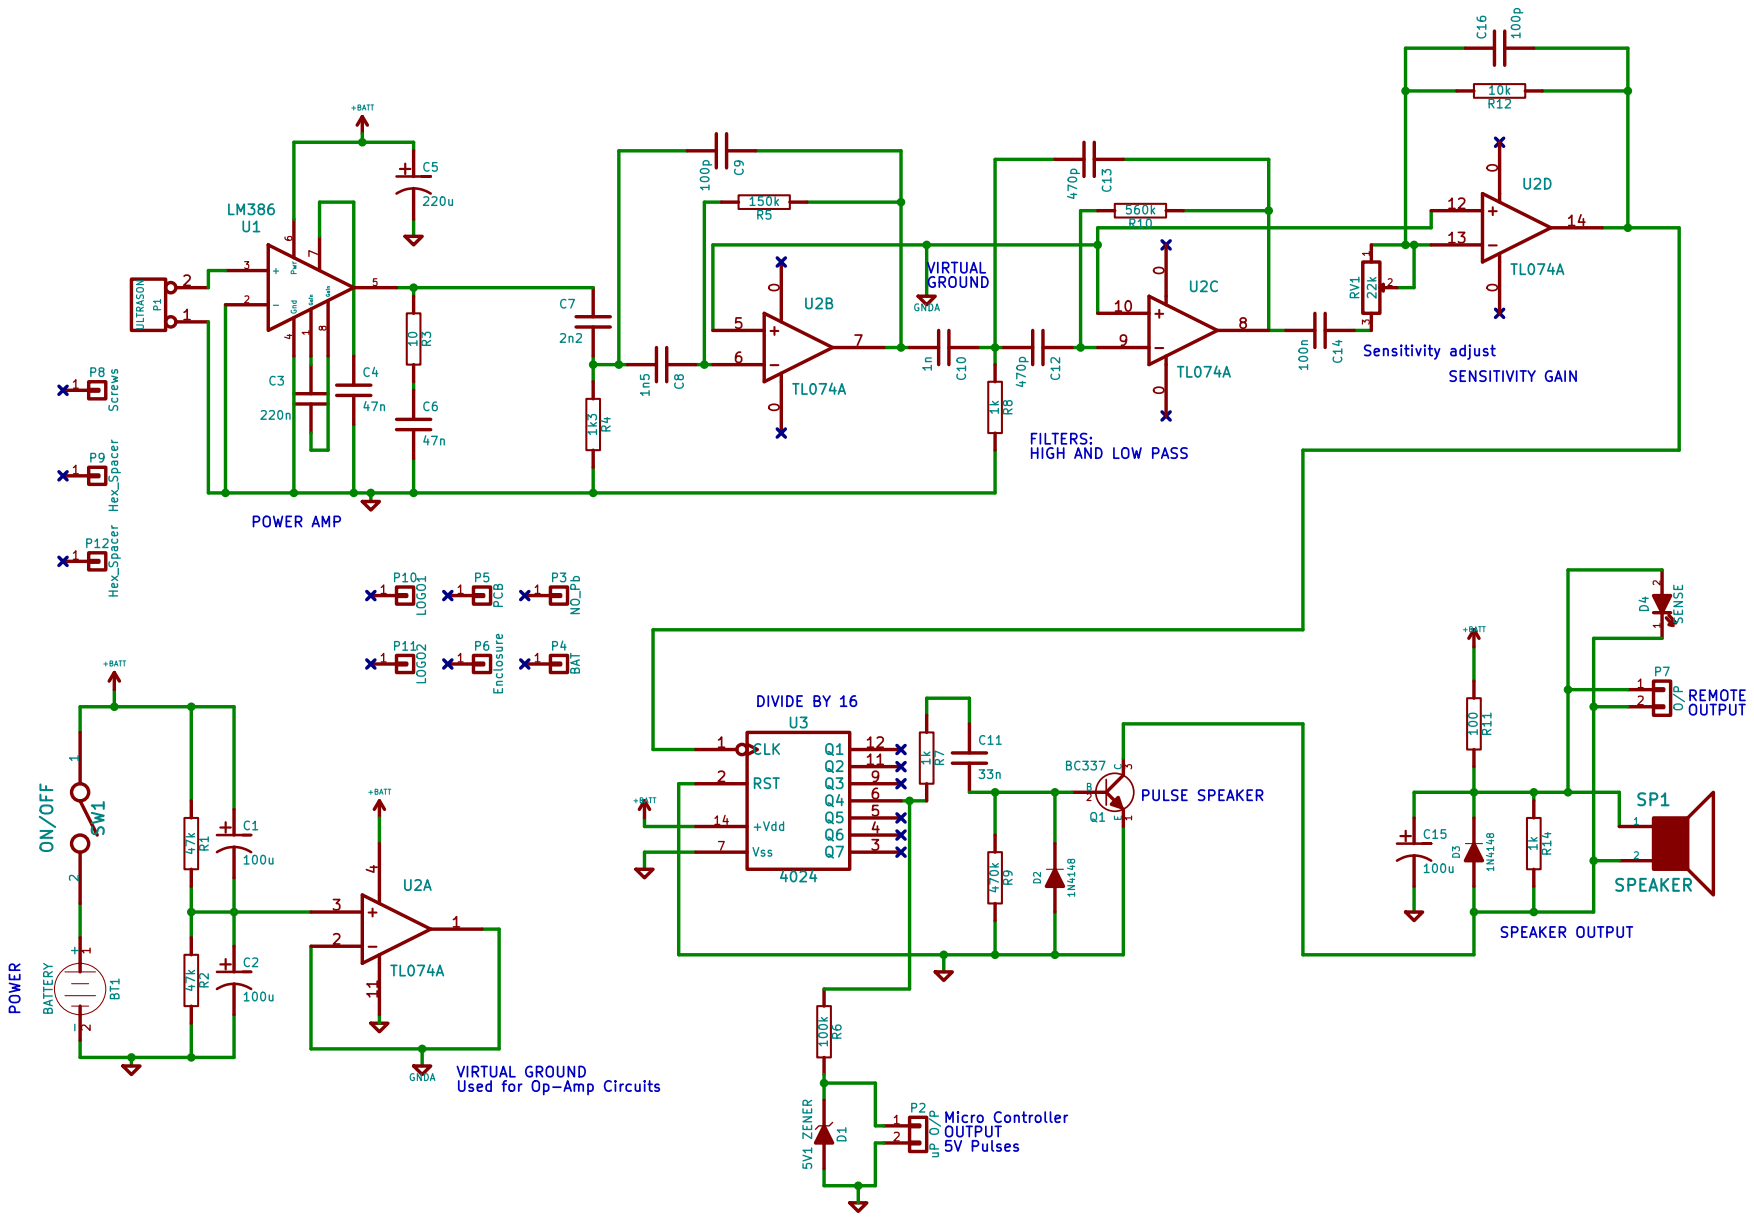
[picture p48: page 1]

FILTERS:
HIGH AND LOW PASS

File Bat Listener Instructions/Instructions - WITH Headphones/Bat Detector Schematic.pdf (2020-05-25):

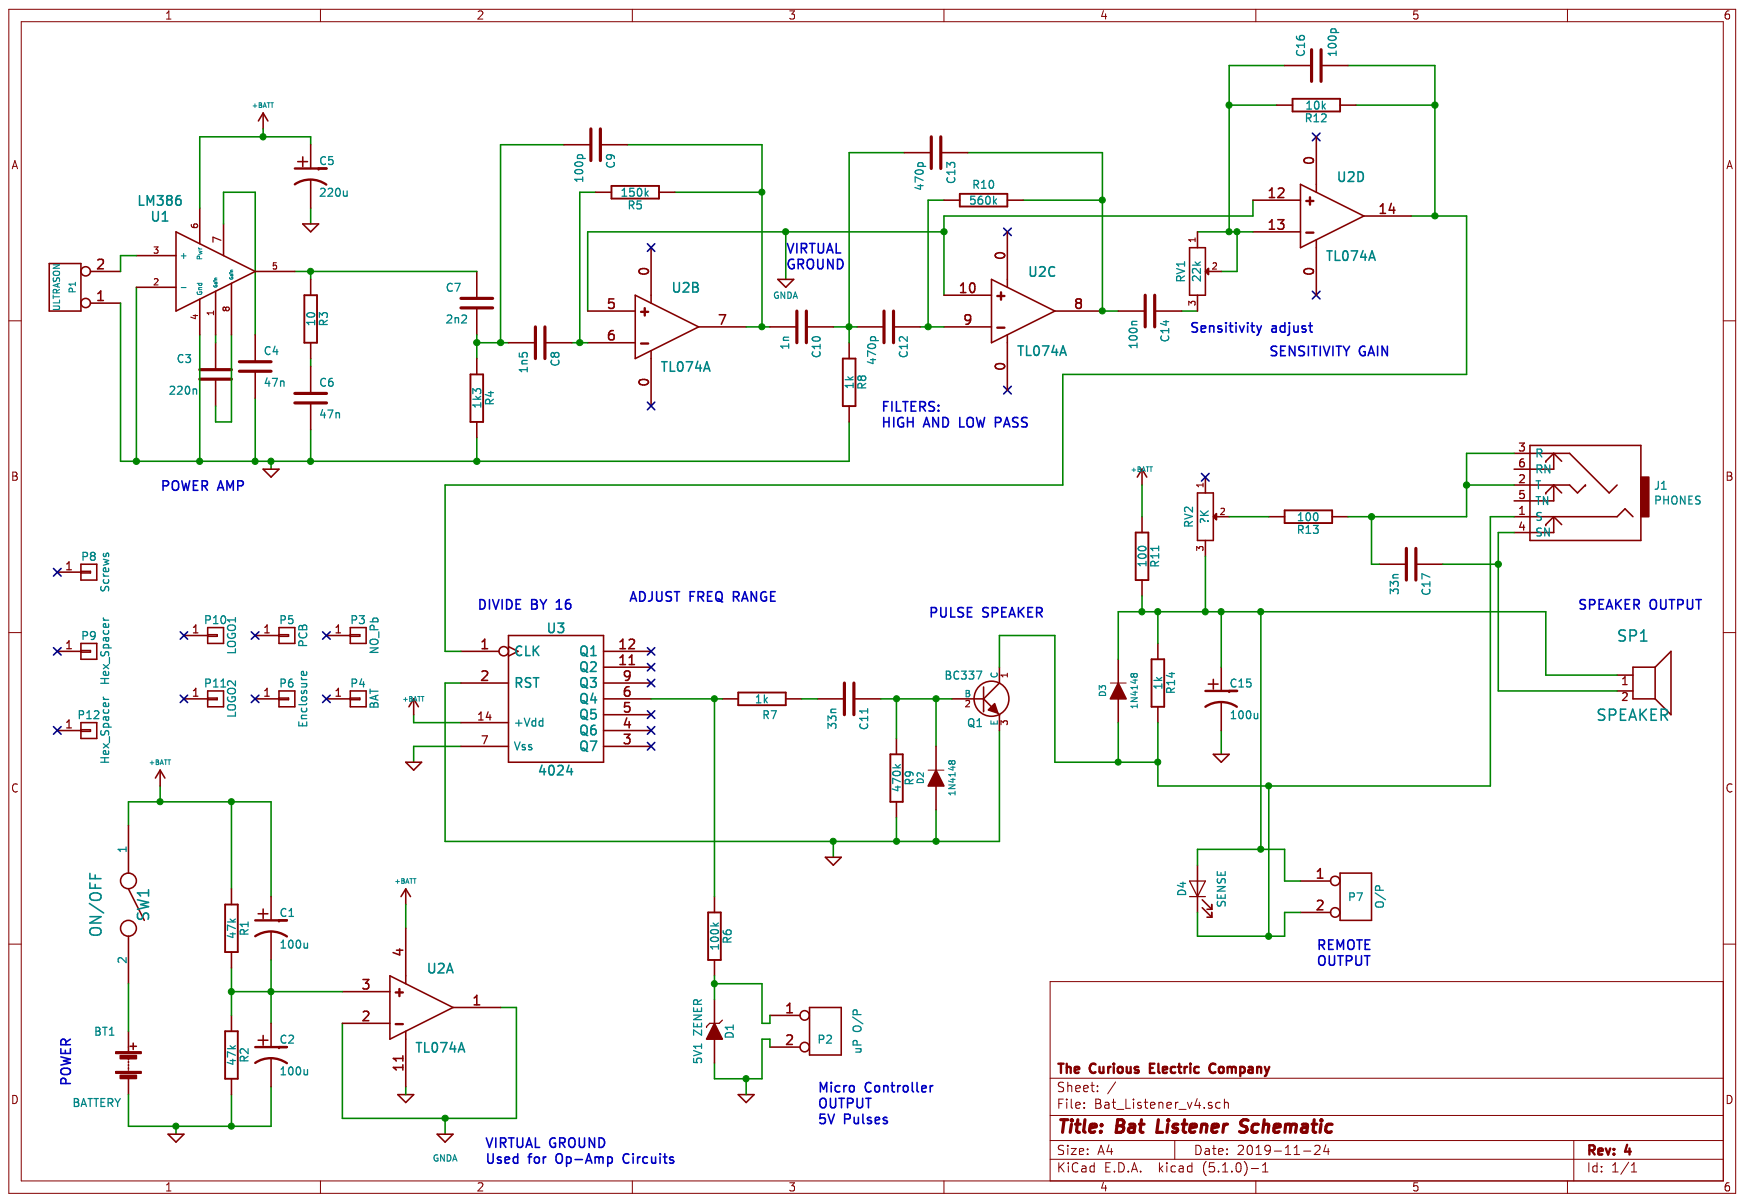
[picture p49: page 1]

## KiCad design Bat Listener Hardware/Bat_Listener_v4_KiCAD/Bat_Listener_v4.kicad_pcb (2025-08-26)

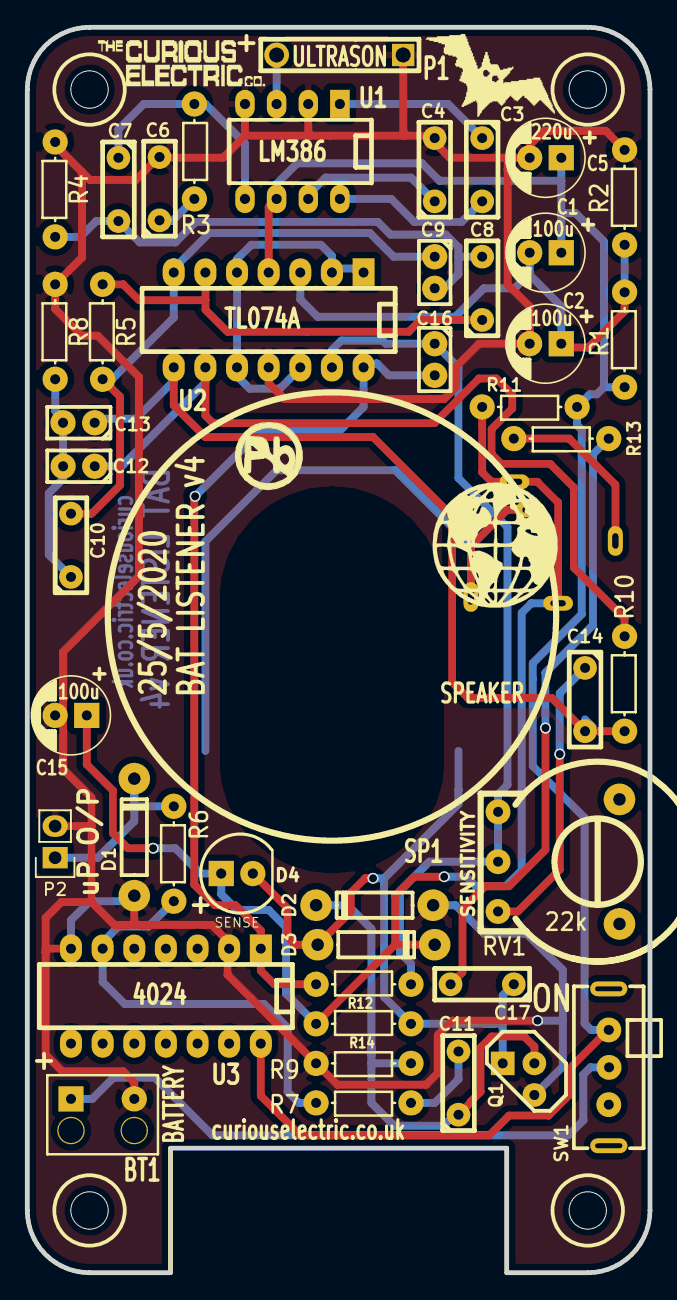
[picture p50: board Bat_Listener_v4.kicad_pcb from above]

Board: 2 copper layers, 50.0 x 100.0 mm, 51 parts (1 on the bottom side), 29 nets.

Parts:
BT1: BATTERY; Batt_Connector_Strain_Relief
C1, C2, C15: 100u; C_1V7_TH
C3: 220n; C1_wide_lg_pad
C4, C6: 47n; C1_wide_lg_pad
C5: 220u; C_1V7_TH
C7: 2n2; C1_wide_lg_pad
C8: 1n5; C1_wide_lg_pad
C9, C16: 100p; C1_lg_pad
C10: 1n; C1_wide_lg_pad
C11, C17: 33n; C1_wide_lg_pad
C12, C13: 470p; C1_lg_pad
C14: 100n; C1_wide_lg_pad
D1: 5V1 ZENER; TH_Diode_1
D2, D3: 1N4148; TH_Diode_1
D4: SENSE; TH_LED-5MM
J1: PHONES; TH_3_5mm_Jack_oval_holes
P1: ULTRASON; TH_Ultra_sonic_Rx
P2: uP O/P; TH_Pin_Header_Straight_1x02
P3: NO_Pb; PH_LOGO_NO_Pb
P4: BAT; Bat_Logo
P5: PCB; PCB_50x100mm_PP3_CutOut
P10: LOGO1; TCEC_Words_13mm
P11: LOGO2; CuriousElectric_globe_10mm
Q1: BC337; NPN_BC337
R1, R2: 47k; TH_Resistor_1
R3: 10; TH_Resistor_1
R4: 1k3; TH_Resistor_1
R5: 150k; TH_Resistor_1
R6: 100k; TH_Resistor_1
R7, R8, R14: 1k; TH_Resistor_1
R9: 470k; TH_Resistor_1
R10: 560k; TH_Resistor_1
R11, R13: 100; TH_Resistor_1
R12: 10k; TH_Resistor_1
RV1: 22k; TH_PRESET_Thumb_Side
SP1: SPEAKER; TH_SPEAKER_36mm
SW1: ON/OFF; SW_SPDT_R_Angle_ALIEX
U1: LM386; DIP-8_300_ELL
U2: TL074A; DIP-14__300_ELL_lg_pad
U3: 4024; DIP-14__300_ELL_lg_pad

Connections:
+BATT: C1.1, C5.1, R1.1, R11.1, SW1.1, U1.6, U2.4, U3.14
GND: BT1.2, C2.2, C4.2, C5.2, C6.2, C15.2, D1.1, D2.1, P1.1, P2.2, Q1.3, R2.2, R4.2, R8.2, R9.2, U1.2, U1.4, U2.11, U3.2, U3.7
GNDA: U2.1, U2.2, U2.5, U2.10, U2.12
unnamed: BT1.1, SW1.2
unnamed: C1.2, C2.1, R1.2, R2.1, U2.3
unnamed: C3.1, U1.1
unnamed: C3.2, U1.8
unnamed: C4.1, U1.7
unnamed: C6.1, R3.2
unnamed: C7.1, R3.1, U1.5
unnamed: C7.2, C8.2, C9.2, R4.1
unnamed: C8.1, R5.2, U2.6
unnamed: C10.1, C12.2, C13.2, R8.1
unnamed: C9.1, C10.2, R5.1, U2.7
unnamed: C11.1, D2.2, Q1.2, R9.1
unnamed: C11.2, R7.1
unnamed: C12.1, R10.2, U2.9
unnamed: C13.1, C14.2, R10.1, U2.8
unnamed: C14.1, RV1.3
unnamed: C15.1, D3.2, D4.1, J1.2, J1.3, R11.2, R14.1
unnamed: C16.1, R12.2, RV1.1, RV1.2, U2.13
unnamed: C16.2, R12.1, U2.14, U3.1
unnamed: C17.1, D3.1, D4.2, Q1.1, R14.2, SP1.2
unnamed: C17.2, R13.1
unnamed: D1.2, P2.1, R6.2
unnamed: J1.1, R13.2
unnamed: J1.5, J1.6, SP1.1
unnamed: P1.2, U1.3
unnamed: R6.1, R7.2, U3.6

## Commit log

2015-11-30 Upload v2 design files
    [Elektor_bat_detector.sch, Elektor_bat_detector_v3.brd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]
2015-12-03 Initial set of files
    2015 12 3
    [2015_12_3_bat_listener_case_v2.dxf, Elektor_bat_detector.sch, Elektor_bat_detector_v3.brd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]
2017-01-10 Update to 2016 Bat Listener files
    Large change of all files to the new design
    [2015_12_3_bat_listener_case_v2.dxf, Bat Listener 2016 Enclosure v4.dxf, Bat_Listener_2016_BOM.xls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]
2018-09-16 Updates Instructions
    A few changes for the new design case
2020-05-25 Updated new PCB version
    [Bat_Listener_2016_BOM.xls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]
2020-08-08 Update of PCB and Enclosure Files
    Added headphone socket.
    [Bat Listener 2016 Enclosure v4.dxf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]
2020-11-21 Small changes to PCB and enclosure
2021-11-08 Update README.md
    https://forum.kicad.info/t/warning-avoid-all-links-to-kicad-pcb-org-use-kicad-org/31521
2024-08-05 Updated enclosure design - added 3D model
    [Bat Listener 2016 Enclosure v4.dxf, Ultrasonic Case Lid.stl, Ultrasonic Case.step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]
2024-09-06 moved schematic.
    [Bat_Listener_v4.kicad_sch]
2025-08-26 updated instructions - small change
    [Bat_Listener_v4.kicad_pcb]
2026-08-27 updated to new KiCAD version
2026-08-28 Updated instructions. Added github link and large image of final PCB
